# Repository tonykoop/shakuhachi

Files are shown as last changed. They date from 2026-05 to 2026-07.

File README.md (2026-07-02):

# Shakuhachi — Engineering Documentation for the Japanese End-Blown Bamboo Flute

> *A solid-billet hardwood adaptation of the shakuhachi, with parametric design for an 11-key family and a build-packet for the first prototype: 1.8-shaku D4 in cherry, bored using the headstock-driven deep-bore drilling technique on the lathe.*

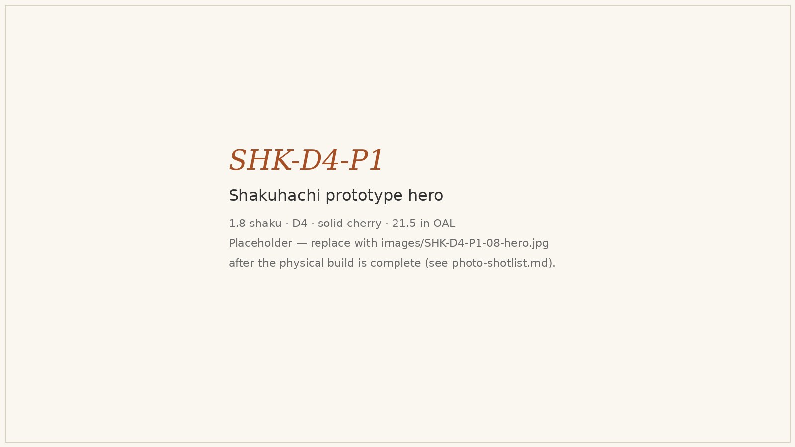
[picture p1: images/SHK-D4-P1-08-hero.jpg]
Hero — SHK-D4-P1 placeholder, replace after build

*Placeholder hero plate: SHK-D4-P1, solid cherry, 21.5 in OAL, tuned to D4. Replace this file with the canonical 35° oblique product shot after the physical build is complete — see [photo-shotlist.md](photo-shotlist.md) shot 08.*

## Release status

**Status:** L2 V5 build-packet candidate. The packet set is in place: README rewrite, design docs, BOM/sourcing/cut list/validation, assembly manual, risks, Wolfram starter, drawings, OpenSCAD reference, print/deck artifacts, and the public build-log site all exist. V5 artifacts (`visual-output-register.csv`, `cad/mcp-session-log.md`, `family-spec.csv`) added 2026-05-29.

The remaining blockers are explicit:

- **No measured prototype data yet.** `validation.csv` is a build-and-measure plan, not a filled results log.
- **Hero media is still provisional.** The current hero is a placeholder plate until SHK-D4-P1 is physically built and photographed.
- **OpenSCAD source is pending measurement confirmation.** `cad/shakuhachi_master.scad` is the current geometry source; dimensions are first-order estimates — not fabrication authority until prototype bore/utaguchi correction loop closes.

**Next action:** build SHK-D4-P1, ingest the first measured Ro fundamental with `record_measurement.py`, then either export a confirmed drawing/render set from CAD or keep the repo explicitly framed as an OpenSCAD-first prototype packet.

## What this is

Engineering documentation and parametric design for the **shakuhachi** (尺八) — a Japanese end-blown bamboo flute traditionally tuned in a minor pentatonic with five finger holes. This repository combines:

1. **A parametric design table** ([`shakuhachi-design-table.xlsx`](shakuhachi-design-table.xlsx)) covering an 11-key family (C4 through higher), with formulas that derive every build dimension from the target fundamental, plus a Wolfram-Cloud notebook spec for honkyoku phrase synthesis and meri / kari pitch-shift modeling.
2. **A build packet for SHK-D4-P1** — the first physical prototype, 1.8-shaku D4 in solid cherry. See [`design.md`](design.md) for the governing acoustic model, [`bom.csv`](bom.csv), [`cut-list.csv`](cut-list.csv), [`validation.csv`](validation.csv), and [`assembly-manual.md`](assembly-manual.md). Drawings live in [`drawings/`](drawings/), CAD masters in [`cad/`](cad/), and the public build log in [`site/index.html`](site/index.html).
3. **A practical bore-making path** tied to the still-open [headstock-driven deep-bore drilling](https://github.com/tonykoop/instrument-maker/issues/84) technique on the [`instrument-maker`](https://github.com/tonykoop/instrument-maker) backlog. The 21.5-in cherry bore is what made this technique necessary — the shakuhachi is a perfect fit for it.

Sister projects: [`flutes`](https://github.com/tonykoop/flutes) (NAF — K2 reference, not portable here), [`fujara`](https://github.com/tonykoop/fujara) (long open-pipe stave-built sister), [`transverse-flute`](https://github.com/tonykoop/transverse-flute) (slip-cast open-pipe; packet template baseline).

## Cultural attribution

The shakuhachi descends from Tang-Chinese xiao ancestors imported to Japan in the 7th–8th c., and was central to the practice of *suizen* ("blowing meditation") within the Fuke sect of Zen Buddhism (Edo-period komusō, "emptiness monks"). The Meiji government banned the Fuke sect in 1871; the instrument survived in concert and ensemble use, and modern **Kinko-ryū** and **Tozan-ryū** schools continue traditional practice. Traditional makers in Kyoto, Tokyo, and Hamamatsu still build with **madake bamboo** (*Phyllostachys bambusoides*), urushi-lined bores, and water-buffalo-horn utaguchi inlays. The instruments documented here are **Western luthier-shop adaptations** built in respect for that tradition — not faithful reproductions. Where this packet diverges from tradition (solid hardwood billet, straight bore, oil finish, no urushi) it is documented as such.

## Background — what makes a shakuhachi different

**1. Voicing comes from the utaguchi cut, not a fipple.** The shakuhachi has no fipple block, no slow-air chamber, no whistle-type window. It is a direct end-blown flute: the player rests the lower lip against the utaguchi (a beveled notch cut into the rim) and directs a focused jet of air across its outer edge. This makes the instrument acoustically simple but technically demanding — every note relies on the player's lip and breath shaping.

**2. Five tone holes and a deep modal language.** Four front holes plus one thumb hole on the back, tuned to the Kinko-ryū interval set (+0/+3/+5/+7/+10/+12 semitones above the fundamental). The minor-pentatonic shape gives the instrument its characteristic voice; microtonal pitch-bending via *meri* (chin-down) and *kari* (chin-up) extends each tonal centre by ~50–100 cents.

**3. Length is the key.** A shakuhachi tuned to D4 has the standard length of 1.8 shaku (~21.5 in / 54.5 cm) — the very name 尺八 means "1.8" (one shaku eight sun). Lower keys take longer instruments: 2.4 shaku ≈ A3, 1.6 shaku ≈ E4, etc. The packet covers an 11-key parametric family, but the build-packet first prototype anchors at the canonical 1.8-shaku D4.

## The parametric design table

The single engineering-heavy artifact is [`shakuhachi-design-table.xlsx`](shakuhachi-design-table.xlsx). Variables in column A; per-key columns flow right.

**User-set per key:** Bore ID, Wall Thickness, Utaguchi Width / Depth / Angle, Extra Length (allowance for foot trim during tuning).

**Calculated per key:**
- Acoustic length `L_acoustic = c / (2·f_fund)`
- End-correction total (foot ≈ 0.6·r, utaguchi ≈ 1.7·r empirical)
- Effective physical length `L_physical = L_acoustic − δ_total`
- Shaku-length conversion (1 shaku = 11.93 in)
- Hole positions for Ro / Tsu / Re / Chi / Ri / thumb at Kinko-ryū intervals

**Compared to the NAF design table:** the workbook does **not** apply the K2 bore-diameter correction. K2 was derived from fipple-block + slow-air-chamber NAFs; the shakuhachi has neither. K2 columns are intentionally blank for shakuhachi rows. See [`design.md` § Empirical-correction guard](design.md).

## Build packet — SHK-D4-P1

| Parameter | Value | Notes |
| --- | --- | --- |
| Fundamental | 293.665 Hz (D4) | 1.8-shaku canonical |
| Physical length | 21.50 in (54.61 cm) | 1.80 shaku |
| Bore ID | 0.787 in (20 mm) | H7 reamed from 0.5/0.625/0.75 steps |
| OD | 1.10 in | Wall ≥ 0.150 in everywhere |
| Material | cherry (qtr-sawn) | backup: hard maple, walnut |
| Tone holes | 5 (4 front + thumb) | Ø 0.276 in starting; file-tuned |
| Utaguchi | 0.787 W × 0.315 D × 32° | hand-cut + filed |
| Bore-making path  | headstock-driven deep-bore | [`instrument-maker#84`](https://github.com/tonykoop/instrument-maker/issues/84) |

**Why SHK-D4-P1 is the right first prototype**, in priority order:

1. **It's the canonical shakuhachi.** The 1.8-shaku D4 is the standard reference instrument in both Kinko-ryū and Tozan-ryū traditions. Anything else is a divergence; this one is the centre of gravity.
2. **It's the boundary condition for the family.** All other family members' physical lengths, bore IDs, and end corrections derive from the same model. SHK-D4-P1's measured fundamental refines δ_utaguchi for the rest.
3. **It exercises the deep-bore drilling technique cleanly.** 21.5 in × 0.787 in is the depth-to-diameter ratio that motivated the headstock-driven technique on the [instrument-maker backlog](https://github.com/tonykoop/instrument-maker/issues/84). Building it validates the technique alongside the instrument.
4. **It's structurally safe.** Wall thickness with the planned OD (1.10 in) is 0.157 in nominal — comfortable margin over the 0.150 in minimum even at the widest tone hole.
5. **It's empirically anchored.** Traditional 1.8 shaku ↔ D4 is well-attested across centuries of Japanese makers, so a wrong prediction is immediately and unambiguously wrong (vs. being absorbed into measurement noise on a less-canonical key).

Detail in [`design.md`](design.md), [`assembly-manual.md`](assembly-manual.md), and [`risks.md`](risks.md). The validation plan with measurement-driven empirical loop is in [`validation.csv`](validation.csv).

## Repository structure

```
shakuhachi/
├── shakuhachi-design-table.xlsx   parametric workbook (11-key family)
├── design.md                      governing model + first-prototype design
├── bom.csv                        bill of materials, 16 line items
├── sourcing.csv                   suppliers + SKUs
├── cut-list.csv                   blank → finished part operations
├── validation.csv                 measurement-driven test plan
├── assembly-manual.md             13-step shop manual
├── supplier-rfq.md                RFQ template for outside vendors
├── drawing-brief.md               drawing list, datums, tolerances
├── visual-bom-brief.md            single-sheet BOM plate spec
├── photo-shotlist.md              hero + process + detail shots
├── risks.md                       red-team risk register w/ tests
├── wolfram-starter.wl             Wolfram parametric model
├── cad/                           OpenSCAD master + readme
├── cnc/                           pipeline scope notes (out-of-scope for body)
├── drawings/                      6 SVGs (overall, bore section, utaguchi,
│                                  hole template, vise fixture, hole jig)
├── images/                        photos (populated during build)
├── evolution/                     evolution-pipeline Stage 0 intake (master
│                                  manifest, design-intent, revisions; Gate A
│                                  not yet run)
└── site/index.html                public build-log page
```

## Status

- **Repo:** packet generated, close-ready for human release review.
- **First prototype (SHK-D4-P1):** dimensions specified, validation plan written, risk register filed; **no physical build yet**.
- **Family roll-out:** queued; reads forward from the empirical correction the first measurement produces.

## How to read this repo

If you're a maker / reviewer evaluating the engineering: start with [`design.md`](design.md) § Governing Model, then [`risks.md`](risks.md), then [`assembly-manual.md`](assembly-manual.md). The CSVs are the ground truth for shop work; the SVGs in [`drawings/`](drawings/) are the manufacturing references.

If you're an outside builder: the [`site/index.html`](site/index.html) public build log is the friendly front door.

## License

Code, drawings, and design documentation: [CC BY 4.0](LICENSE).

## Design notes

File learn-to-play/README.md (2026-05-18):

# learn-to-play / Shakuhachi (D)

Starter songbook for the D shakuhachi from the build packet. Generated by the sheet-music skill.

The shakuhachi is an end-blown bamboo flute with a quiet attack, flexible pitch, and expressive meri/kari shading.

Range: **D4 - D6 (two octaves). Five-hole pentatonic core with cross-fingered diatonic notes.**

## Folder map
| Folder | Contents |
|---|---|
| `00-warmup-scales/` | D minor pentatonic range walk, breath-tone intervals, meri/kari pitch-bend drill |
| `01-easy/` | Three slow Japanese public-domain folk melodies |
| `02-intermediate/` | Two modal studies with longer breath arcs |
| `03-original/` | *Bamboo Rain* - Heifer Zephyr original |
| `fingering-charts.svg` | D minor pentatonic fingering chart, D4-D6 |

## Repertoire

### 01-easy
| Tune | Tradition |
|---|---|
| Sakura Sakura | Trad Japanese folk song (pre-1900) |
| Hotaru Koi | Trad Japanese folk song (pre-1900) |
| Kagome Kagome | Trad Japanese children's song (pre-1900) |

### 02-intermediate
| Tune | Tradition |
|---|---|
| Edo Lullaby | Trad Japanese lullaby (pre-1900) |
| Rokudan Breathing Study | Inspired by koto/shakuhachi practice forms; original study |

### 03-original
**Bamboo Rain** - 24-bar through-composed meditation, D minor pentatonic, quarter=50.

## Notes on notation
Meri/kari markings are written as comments in the ABC header. Treat grace notes as slow pitch inflections unless a note says otherwise.

## L2 readiness and known gaps
This starter songbook is ready for L2 review as a playable packet draft: ABC melodies, per-tune notes, static fingering summaries, warmups, and a top-level chart are present. Known gaps: generated audio, MusicXML, LilyPond, MIDI, and printable songsheets are skipped until the shared render dependencies are available; fingering charts need builder review against the final hole layout.

## License
Arrangements MIT-licensed by Tony Koop / Heifer Zephyr. Public-domain tune provenance is listed in each `notes.md`. Original studies are MIT-licensed for performance, recording, arrangement, and adaptation.

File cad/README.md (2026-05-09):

# `cad/` — CAD references for SHK-D4-P1

- `shakuhachi_master.scad` — parametric OpenSCAD master for the finished SHK-D4-P1 geometry. Renders the body with the bore subtracted, utaguchi notch subtracted, and five tone holes drilled at first-pass acoustic stations. Updates to the bore/length/correction parameters propagate through.

## Generate STL

```bash
openscad -o shakuhachi_d4_p1.stl shakuhachi_master.scad
```

## Notes

- The master is a **CAD reference**, not a CNC toolpath. The build path is bore-first via the headstock-driven deep-bore drilling technique (`instrument-maker#84`), followed by outside turn between centers — see `assembly-manual.md`.
- Tone-hole positions and diameters in the SCAD file are first-pass acoustic stations; the as-built instrument is bisque-style tuned and will deviate (holes 5–15 mm closer to the foot, diameters slightly enlarged via filing).
- A SolidWorks master layout (Part + Design Table) for SHK-D4-P1 is planned but not in this packet drop. When generated, it will live under `sw-reference/` with the same file naming convention as `fujara/sw-reference/`.

## Status and next handoff

- **Current source of truth in-repo:** `shakuhachi_master.scad` plus the workbook and drawing set.
- **What is intentionally missing:** no checked-in SolidWorks part/design-table handoff yet, because the first measured prototype should confirm `δ_utaguchi` before a second CAD master is frozen.
- **Next CAD action after the first build:** export one confirmed render and one dimensioned drawing from the measured geometry, then decide whether a `sw-reference/` drop adds value or just duplicates the OpenSCAD master.

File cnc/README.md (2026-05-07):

# `cnc/` — CNC toolpaths for SHK-D4-P1

This packet's primary build pipeline is **lathe + drill press**, not CNC router. The CNC pipeline is documented for completeness and for siblings that may benefit from CNC pocketing of fixture parts.

## Out-of-scope for SHK-D4-P1

- **Body bore.** The 21.5-in deep bore is drilled with the headstock-driven deep-bore drilling technique on the lathe (see `instrument-maker#84` and `assembly-manual.md` § Step 5). CNC routers cannot match the depth-to-diameter ratio without specialty tooling that doesn't make sense for a one-off prototype.
- **Body outside turn.** Between centers on the wood lathe; CNC turning a 21.5-in cylinder would be a wasted setup.
- **Tone holes.** Drill press with the V-cradle jig (SHK-BOM-007). CNC drilling on a curved cylindrical surface requires a 4-axis fixture that isn't available in Tony's shop.

## In-scope (optional, future)

- **Tailstock vise (SHK-fixture-vise) plate cutouts.** If the steel-angle vise (SHK-CUT-010) is fabricated using a CNC plasma cutter, drop the DXF in `cnc/SHK-fixture-vise.dxf`. Not required — bandsaw + drill press works.
- **Tone-hole jig V-cradle (SHK-fixture-hole-jig).** If made from MDF or plywood with a CNC router, the V-radius matching Ø 1.10 OD is easier to cut accurately than by bandsaw. DXF / 1/4-in endmill toolpath would live at `cnc/SHK-fixture-hole-jig.gcode`. Not required.

## Why this doc exists

Reviewer expectation under instrument-maker-v4 is that every packet has a `cnc/` folder with at least a README explaining the manufacturing pipeline. This file documents an explicit "no CNC for body" decision so a future agent doesn't accidentally generate CNC programs for an instrument that doesn't need them.

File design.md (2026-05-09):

# Shakuhachi — Design Document

## Source And Scope

- Date: 2026-05-07
- Repo: `tonykoop/shakuhachi`
- Source workbook (this repo): [`shakuhachi-design-table.xlsx`](shakuhachi-design-table.xlsx) — sheet `Shakuhachi`, 11-key parametric family from C4 (#40) through B4 (#50) plus higher.
- Sister design table referenced for cross-validation: `Musical Instruments V2.xlsx` → sheet `Shakuhachi`.
- Sister repos: [`flutes`](https://github.com/tonykoop/flutes) (NAF; K2 reference — see "Empirical-correction guard" below), [`fujara`](https://github.com/tonykoop/fujara) (closest open-pipe wood neighbor), [`transverse-flute`](https://github.com/tonykoop/transverse-flute) (slip-cast open-pipe — packet template).

This document is the parametric design narrative behind the rest of this build packet (`bom.csv`, `cut-list.csv`, `validation.csv`, `assembly-manual.md`, `risks.md`, drawings, site, etc.). The companion .xlsx is the editable parametric surface; `design.md` is the explanation.

## Design Intent

Build a small, manufacturable family of solid-billet shakuhachi (1.8 shaku D4 first; sized siblings later) on Tony's lathe + CNC pipeline, with the bore drilled using the **headstock-driven deep-bore drilling** technique on square stock before the outside is turned round. Document the acoustic model honestly — open-pipe physics with explicit, separately-tracked end corrections — so the first prototype's measured pitch can drive a corrections database update rather than a hand-tuned one-off. Cultural framing stays respectful and factual: this is a Western luthier-shop solid-billet build; traditional split-bamboo shakuhachi (madake, urushi-lined) is a separate craft with its own lineage.

The first prototype is **SHK-D4-P1**: 1.8-shaku solid-billet hardwood D4, no urushi lining, intentionally undersized hole bores so a bisque-style tuning step can bring it inside ±10 cents.

## Governing Model

Open-open pipe with two open ends — the lower (foot) is a free open end; the upper (utaguchi) is a beveled/notched open end with player-jet excitation. First-pass:

```text
f = c / (2 · L_eff)
L_eff = L_physical + δ_foot + δ_utaguchi
δ_foot ≈ 0.6 · r_bore                    # standard open-end correction (Levine/Schwinger)
δ_utaguchi ≈ 1.5 · r_bore to 2.0 · r_bore  # empirical shakuhachi extension; see below
hole_distance_from_foot ≈ L_eff_acoustic · (f_fund / f_hole)
```

`c = 13552 in/s` at 68 °F (1 atm dry air). `f = 440 · 2^((MIDI − 69)/12)`. `cents = 1200 · log₂(measured / target)`.

The standard NAF/Irish-flute 0.6·r end correction at the foot is well-validated. The **utaguchi** end is harder: the beveled notch + player's lip + jet airspace shift the acoustic open-point upward of the physical rim, so the *effective* extension is larger than 0.6·r. This is why a standard 1.8-shaku (21.5 in / 54.5 cm) physical length sounds D4 (293.66 Hz) — back-solving from `f = c/(2·L_eff)` gives `L_eff ≈ 23.1 in`, leaving `1.6 in` to be split between two end corrections, dominated by the utaguchi end. Per-end ≈ 1.5·r–2.0·r is the empirical band Western and Japanese makers report; it is **not** the same correction as a flanged open pipe (~0.85·r) and it is **not** the NAF K2 correction. Document it as a shakuhachi-specific empirical extension and refine after measurement.

## Empirical-correction guard

Tony's NAF K2 bore-diameter corrections (`+0.4%` at 0.875 in, `+1.0–1.6%` ≥1.125 in, `−0.7 to −6.0%` ≤0.75 in — see `flutes` and `references/acoustic-models.md` in instrument-maker-v4) were derived from 150+ Native American flutes with fipple block, slow-air chamber (SAC), and a fipple-driven embouchure. **A shakuhachi has none of those features** — no SAC, no fipple, no SAC→bore window — so K2 does not transfer. This packet uses the standard 0.6·r foot correction plus the explicit shakuhachi-specific utaguchi extension above. K2 columns in the workbook are intentionally left blank for shakuhachi rows.

## Hardware Alignment

- Pipeline: **CNC + lathe + hand-finished utaguchi**, not split-bamboo. Tony's shop is set up for solid-billet drilling and turning, and madake import is impractical for a study series.
- Bore-making strategy: **headstock-driven deep-bore drilling on square stock** ([`tonykoop/instrument-maker#84`](https://github.com/tonykoop/instrument-maker/issues/84)). The bit spins in the lathe headstock (Morse taper → Jacobs chuck); the square blank is gripped in a tailstock-mounted vise with a positive anti-rotation feature (V-block + side clamps); the tailstock quill advances the blank into the bit in short pecks. The bore is established before the outside is turned round, so the round-turning operation later registers off the established bore axis.
- Outside turn: between centers off the bore, after the bore is reamed/lapped to finish ID.
- Utaguchi: hand-cut bevel — chisel + fine file. Optional buffalo-horn or hardwood inlay (water buffalo horn = traditional; lignum vitae or African blackwood = Western substitute).
- Tone-hole boring: drill press with index-fixed jig referenced off the bore axis. Holes start undersized (~7 mm / 0.276 in) and are filed open during tuning.
- Finish: walnut oil + carnauba (food-safe inside; no urushi for the prototype). Note: traditional madake shakuhachi use *urushi* (Japanese lacquer) inside the bore — that workflow is out of scope for this packet but documented for future builds.

## Family Targets — first parametric pass

Eleven-key family from the workbook, computed at 68 °F. Hole frequencies use Kinko-ryū intervals (Ro / Tsu / Re / Chi / Ri / thumb-Ro′) at +0, +3, +5, +7, +10, +12 semitones.

| Member ID  | Key | Shaku | Fund (Hz) | L_acoustic (in) | δ_total (in) | L_physical (in) | Bore ID (in) | Bore-OD wall (in) | Status |
| --- | --- | --- | ---:| ---:| ---:| ---:| ---:| ---:| --- |
| SHK-C4-001 | C4  | 1.91 | 261.626 | 25.91  | 1.65  | 24.26  | 0.787 | 0.236 | Family — defer |
| SHK-D4-001 | D4  | 1.80 | 293.665 | 23.08  | 1.55  | 21.53  | 0.787 | 0.236 | **First prototype (SHK-D4-P1)** |
| SHK-Eb4-001| Eb4 | 1.70 | 311.127 | 21.78  | 1.50  | 20.28  | 0.787 | 0.236 | Family — queued |
| SHK-E4-001 | E4  | 1.60 | 329.628 | 20.55  | 1.45  | 19.10  | 0.787 | 0.236 | Family — queued |
| SHK-F4-001 | F4  | 1.50 | 349.228 | 19.40  | 1.30  | 18.10  | 0.669 | 0.197 | Family — queued |
| SHK-G4-001 | G4  | 1.30 | 391.995 | 17.28  | 1.20  | 16.08  | 0.669 | 0.197 | Family — queued |
| SHK-A4-001 | A4  | 1.10 | 440.000 | 15.40  | 1.10  | 14.30  | 0.591 | 0.197 | Family — queued |
| SHK-B4-001 | B4  | 1.05 | 493.883 | 13.72  | 1.00  | 12.72  | 0.591 | 0.197 | Family — queued |

Notes:
- `δ_total = δ_foot + δ_utaguchi`, with `δ_foot = 0.6·r_bore` and `δ_utaguchi` chosen empirically so `L_physical` matches the historical shaku-length tradition (D4 1.8 shaku → 21.5 in, F4 1.5 shaku → 18.0 in, etc.). The fitted `δ_utaguchi` is approximately `1.4·r_bore – 2.1·r_bore` across the family — wider than the foot correction.
- Workbook columns (`Bore ID`, `Wall Thickness`) preserve the source values: 0.787 in / 0.236 in for C4–E4, 0.669 / 0.197 for F4–G4, 0.591 / 0.197 for A4–B4.
- "Shaku" column is approximate; the historical naming (1.8, 1.6, 2.4) maps to physical length, not exactly to key. The actual first-pass `L_physical` is what feeds the cut list.

### Tone holes for SHK-D4-P1 (D4 standard 1.8-shaku)

Acoustic stations from the foot, computed as `d = L_acoustic · f₀ / f_hole`. Physical reality will be 5–15 mm shorter (i.e. holes nearer the foot) once finite-hole-diameter corrections are applied during tuning. Hole diameters start undersize and open during validation.

| Hole | Note (Kinko-ryū) | Δsemitones | f_hole (Hz) | Predicted d_foot (in) | Initial bore Ø (in) | Ergonomic notes |
| --- | --- | ---:|---:| ---:|---:| --- |
| Hole 1 (Tsu)  | F4 | +3 | 349.228 | 19.40 | 0.276  | Front, lowest finger (right pinky) |
| Hole 2 (Re) | G4 | +5 | 391.995 | 17.29 | 0.276  | Front (right ring) |
| Hole 3 (Chi)  | A4 | +7 | 440.000 | 15.40 | 0.276  | Front (left middle) |
| Hole 4 (Ri) | C5 | +10 | 523.251 | 12.95 | 0.276  | Front, highest (left index) |
| Thumb (Ro′) | D5 | +12 | 587.330 | 11.54 | 0.276  | Back, opposite/just below Hole 4 |

Tuning workflow assumes holes are **filed slightly open** (not enlarged with the drill) so each cents-flat measurement converts directly to a known file-pass action. See `assembly-manual.md` step 7 and `validation.csv` rows for SHK-D4-P1.

### Utaguchi geometry (first-pass)

| Parameter | Value | Source / rationale |
| --- | --- | --- |
| Notch width | 0.787 in | = bore ID (full bore opening) |
| Notch depth | 0.315 in | ~0.40 · bore ID — typical Kinko-ryū depth |
| Inner bevel angle | 32° | Workbook standard; Kinko-ryū makers report 28–35° |
| Outer-edge profile  | Round-over | 0.020–0.030 in radius — softens chip on overblowing |
| Inlay (optional) | 0.060 in | Buffalo horn / lignum vitae block, 0.5 in × 0.787 in × 0.060 in, mortised flush |

The utaguchi profile dominates first-prototype voicing far more than millimeter-scale bore tuning — plan time for hand-shaping iterations.

## Manufacturing Strategy (summary)

Detail in `assembly-manual.md`. Headlines:

1. Mill 1×1×24 in square hardwood blanks on the table saw + planer. Quarter-sawn cherry / hard maple / black walnut for SHK-D4-P1.
2. Center-mark both ends; cross-mark the bore axis with awl + center-finder.
3. Headstock-driven deep-bore drilling per [`instrument-maker#84`](https://github.com/tonykoop/instrument-maker/issues/84):
   - Pilot bit (3/8 in / 9.5 mm) brad-point, lathe MT2 → Jacobs chuck, square blank in tailstock vise.
   - Step up: 1/2 in (12.7 mm) → 5/8 in (15.9 mm) → 3/4 in (19.05 mm) → final 0.787 in (20 mm) reamer or step-down endmill in collet chuck.
   - Pecks ≤ 1.5 in deep; retract to clear chips.
4. Mount blank between centers using the bore as the registration axis (pin centers in the bore). Turn the outside round to 1.10 in OD — modest profile, no decorative beads on prototype.
5. Cut blank to 21.5 in finish length; square the foot end.
6. Lay out tone holes from foot using a paper wrap template; drill undersized (7 mm) on the drill press with the bore axis indexed.
7. Cut utaguchi: bandsaw rough notch → chisel inner bevel to 32° → flat-file → buffer the round-over.
8. Bisque-style tuning: stop all holes, blow Ro, measure cents — file utaguchi or bore foot to bring fundamental within range; then file each hole open in 0.5 mm steps to bring its sounded note within ±10 cents.
9. Oil finish — walnut oil flooded inside the bore and outside; let cure; carnauba wax buff outside only.

## Validation Plan

- **Stage 1 (post-bore):** measure ID at foot, mid, and top with a bore gauge; record three diameters per station to catch ovalization.
- **Stage 2 (post-turn):** measure OD at five stations; verify wall ≥ 0.150 in everywhere (avoid splitting under hole drilling).
- **Stage 3 (post-utaguchi):** blow Ro fundamental, measure with tuner against `f₀ = 293.665 Hz`. Target ±25 cents pre-tuning, ±10 cents post-tuning.
- **Stage 4 (per hole):** open one hole at a time (others closed), record cents error vs target. File open in 0.5 mm increments; remeasure.
- **Stage 5 (octave):** overblow Ro to Ro′; record cents error vs `587.330 Hz`. Octave error >25 cents indicates bore taper or utaguchi geometry; reshape rather than tone-hole-tune.

Each measurement gets a row in `validation.csv` — environment columns (temp, RH, tuner make/model) are mandatory because shakuhachi pitch shifts ~3 cents/°C.

## Open Assumptions

1. **Utaguchi correction `~1.5–2.0·r_bore` per end** is empirical and shakuhachi-specific. SHK-D4-P1 will produce a single data point; the correction will be re-fit on `record_measurement.py` ingest.
2. **Bore is straight cylindrical** (not tapered). Traditional madake shakuhachi has internal taper from the natural bamboo + urushi build-up. Solid-billet straight bore is acoustically simpler but tonally less complex; documented as a planned divergence.
3. **Hole diameters are uniform 0.276 in (7 mm) starting size**. Real shakuhachi often have slightly larger holes (8–10 mm) to flatten higher overtones. Starting smaller leaves room to file open during tuning.
4. **Wood species sensitivity not yet measured.** SHK-D4-P1 is cherry. Differences in modulus / density between cherry / hard maple / black walnut will affect the structural margin around hole walls but should not significantly affect pitch in a sealed-bore build.
5. **No urushi lining.** Western prototype is oil-sealed; pitch stability under humidity changes will be measured over 30 days but no urushi-equivalent damping correction is applied.
6. **Player calibration absorbed into utaguchi correction.** Tony is the test player; embouchure variation between players will shift measured pitch by 5–20 cents. Validation rows note "player = TK" so cross-player corrections can be added later.

## Highest-risk Unknowns

| Risk | Trigger | Test |
| --- | --- | --- |
| Bore wander on 21.5-in deep bore | Pilot bit deflection on long blank | Scrap-stock validation row; bore-axis runout check at 6/12/18″ |
| Utaguchi geometry mistuned beyond filing recovery | Bevel angle wrong, notch too deep | Cut shallow; measure fundamental; deepen incrementally |
| Wall thickness too thin around hole 4 / thumb | Wall ≈ 0.150″, hole Ø 0.394″ → 38% wall loss | Wall-thickness map post-turn; abort if any station < 0.140″ |
| Octave (Ro→Ro′) > 25 cents off | Bore-axis ≠ acoustic axis, or taper drift | Stage-5 measurement; root cause = bore, not hole |
| Foot end-correction assumption fails on shorter keys | δ_foot scales with r but utaguchi scales weakly | F4 / A4 prototypes will reveal whether δ_utaguchi is constant |

## Empirical Loop

After SHK-D4-P1 is measured, run:

```bash
python3 <instrument-maker-v4-install>/scripts/record_measurement.py \
  --packet . \
  --note-id Ro \
  --measured-hz 293.6 \
  --tuner "Korg OT-120" \
  --environment "shop, 68F, 45% RH"
```

Replace `<instrument-maker-v4-install>` with the local install path for the v4 skill/scripts bundle. This updates `validation.csv`, computes cents error vs `f₀ = 293.665`, and refines the per-family `δ_utaguchi` correction so SHK-Eb4-001 / SHK-F4-001 / etc. predictions tighten before they're cut.

## Cultural Framing

The shakuhachi (尺八) originates from Tang-Chinese xiao ancestors imported to Japan in the 7th–8th c., and was central to the practice of *suizen* ("blowing meditation") within the Fuke sect of Zen Buddhism (Edo period komusō, "emptiness monks"). The Meiji government banned the Fuke sect in 1871; the instrument survived in concert and ensemble use (sankyoku trio with koto + shamisen), and modern Kinko-ryū and Tozan-ryū schools continue traditional practice. Traditional makers in Kyoto, Tokyo, and Hamamatsu still use madake bamboo with urushi-lined bores; the instruments built from this packet are non-Slovak…—correction—non-Japanese Western luthier prototypes that respectfully model the acoustics and finger-hole logic without claiming to replicate the traditional craft. Where this packet diverges from tradition (solid billet, hardwood, straight bore, oil finish) it is documented as such.

## Cross-references

- [`tonykoop/instrument-maker#84`](https://github.com/tonykoop/instrument-maker/issues/84) — headstock-driven deep-bore drilling (technique reference).
- [`tonykoop/flutes`](https://github.com/tonykoop/flutes) — NAF family + K2 derivation (do **not** apply K2 to shakuhachi; see "Empirical-correction guard").
- [`tonykoop/fujara`](https://github.com/tonykoop/fujara) — long open-pipe stave-built sister; closest geometric neighbor.
- [`tonykoop/transverse-flute`](https://github.com/tonykoop/transverse-flute) — slip-cast open-pipe sister; packet template baseline.
- `instrument-maker-v4/references/acoustic-models.md` § "Open-Open Pipes", § "Empirical-correction guard rules".
- `instrument-maker-v4/references/techniques/headstock-driven-deep-bore-drilling.md`.

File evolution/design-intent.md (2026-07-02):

# Design Intent — shakuhachi rev A

- Master CAD: `cad/shakuhachi_master.scad` (sha256: 5e1eab587df07bde368e7b54522ce0b5beb3cecc83d5baec8c92fb0c24edd8a5), driven by `shakuhachi-design-table.xlsx` (sha256: e20c7322fb02a1b126804d6d7b2a8281e23369728cbd3b6d9807a8e49a280e54)
- Function: Solid-billet hardwood shakuhachi (Japanese end-blown bamboo flute adaptation), 11-key parametric family (C4-B4), first prototype SHK-D4-P1 (1.8-shaku D4, cherry). Open-open pipe acoustics: foot end open, utaguchi (blowing edge) end open with player-jet excitation; `f = c/(2*L_eff)`, `L_eff = L_physical + delta_foot + delta_utaguchi`. Bore drilled via headstock-driven deep-bore drilling on square stock before outside turning.
- Environment: hand-played wind instrument; walnut-oil/carnauba finish (no urushi lining for the prototype). No physical build exists yet.
- Target qty: 1 prototype (SHK-D4-P1). Deadline: TBD. Budget/unit ceiling: TBD (bom.csv line items ~$28-68 per tooling/material item).

## Critical dimensions (carry tolerances)

| Feature | Nominal | Tolerance | Why critical | Source |
| --- | --- | --- | --- | --- |
| Physical length (SHK-D4-P1) | 21.53 in | measured Ro fundamental within ±25 cents | fundamental pitch (D4, 293.665 Hz) | design.md Family Targets table (SHK-D4-001) |
| Bore ID | 0.787 in | reamed/lapped finish ID | end-correction magnitude, tone | design.md Family Targets table |
| Wall thickness at bore | 0.236 in | structural min around hole 4/thumb hole (risks.md S1) | avoid blowout during hole drilling | design.md Family Targets table |
| Utaguchi end correction (delta_utaguchi) | ~1.4-2.1 x r_bore (empirical) | pending SHK-D4-P1 measurement, ±25 cents gate | dominant term in L_eff; NOT the NAF K2 correction (risks.md A1/A2) | design.md Governing Model + Empirical-correction guard |
| Tone-hole stations (5: Tsu/Re/Chi/Ri/thumb) | see design.md hole table | filed open during tuning, not enlarged with drill | intonation of Kinko-ryu intervals | design.md "Tone holes for SHK-D4-P1" |
| Foot end correction (delta_foot) | 0.6 x r_bore | standard Levine/Schwinger open-end value | secondary L_eff term | design.md Governing Model |

## Incidental (free for DFM)

- Exterior turned profile/taper styling, optional buffalo-horn or hardwood inlay cosmetic choice (risks.md C2 provenance caveat), non-mating surface finish sheen.

## Must-nots (DFM may never violate)

- Do not apply NAF K2 bore-diameter corrections to shakuhachi rows — a shakuhachi has no SAC/fipple, so K2 does not transfer (risks.md A2, design.md Empirical-correction guard).
- Do not cut sibling family blanks (Eb4 etc.) until the corrected delta_utaguchi from SHK-D4-P1 measurement predicts the next member within ±15 cents (risks.md A1).
- Do not enlarge tone holes with a drill after the initial undersized bore — holes are filed open only, per the tuning workflow (design.md Tone holes section).
- Do not thin the wall below spec around hole 4/thumb hole (risks.md S1 structural risk).
- Utaguchi (blowing-edge) bevel geometry stays hand-refined/tuning-sensitive — out of scope for the OpenSCAD envelope model (V5 woodwind addendum).

## Material intent

- Body: quarter-sawn, kiln-dried cherry (primary), hard maple / black walnut backups (bom.csv SHK-BOM-001).
- Optional inlay: buffalo horn or lignum vitae alternative (bom.csv SHK-BOM-002; provenance caveat risks.md C2).
- Finish: walnut oil + carnauba wax (food-safe inside; no urushi lining for the prototype).
- Forbidden: none recorded beyond the cultural-attribution caveat (risks.md C1 — do not overstate traditional-lineage claims on this Western solid-billet prototype).

## Stage status

Stage 0 intake complete 2026-07-01. Gate A (Alpha shop compile) NOT yet run — no concessions logged, nothing presented as shippable. No physical prototype exists yet (SHK-D4-P1 not yet built).

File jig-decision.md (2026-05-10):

# Jig Decision

| Operation | Jig choice | Reason | Release check |
| --- | --- | --- | --- |
| Deep bore | Headstock-driven drilling setup | Long D4 body needs aligned bore support | Bore exits within tolerance and stays burn-free |
| Utaguchi cut | Angle block plus hand-file finish | Utaguchi geometry controls response | Coupon or scrap cut reviewed before body |
| Hole drilling | V-block with centerline and thumb-hole reference | Keeps five-hole pattern aligned around the body | Hole stations match drawing before enlargement |
| Bore finishing | Reamer/sanding mandrel | Smooth bore response matters more than surface shine | Bore is smooth and diameter is logged |
| Prototype material choice | PVC or hardwood proof before bamboo claim | Separates acoustic validation from traditional material complexity | Validation row identifies actual material |

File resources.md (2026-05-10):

# Resources

## Cultural And Build Context

The packet documents a contemporary workshop adaptation of the shakuhachi. It
should name traditional practice respectfully while making clear that a solid
hardwood or PVC proof body is not a faithful madake bamboo reproduction.

## Sources To Confirm Before L3

- Traditional 1.8 shaku D4 dimensional references.
- Utaguchi angle, depth, and insert geometry from measured examples.
- Kinko-ryu and Tozan-ryu fingering/tuning references for public-facing text.
- Bamboo-vs-hardwood bore correction observations from the first prototype.

## Related Repos

- `tonykoop/flutes` for wind-instrument validation habits. NAF K2 corrections
  are not portable to shakuhachi.
- `tonykoop/fujara` for long open-pipe bore and trimming discipline.
- `tonykoop/transverse-flute` for slip-cast/open-pipe documentation patterns.

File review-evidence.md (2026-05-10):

# Review Evidence

Refs #1.

## Round 3 Scope

- Re-validated the existing root-mode packet as part of the wind build-packet
  sweep.
- Existing packet already contains the key shakuhachi-specific hand tuning:
  utaguchi geometry, bamboo-vs-hardwood/PVC prototype framing, pentatonic
  Kinko-ryu interval plan, and explicit warning that NAF K2 corrections do not
  transfer.
- This packet remains L2/L3-candidate documentation, not a measured build.

## Gates Before Close

- Build SHK-D4-P1 or an equivalent proof body.
- Record Ro fundamental, meri/kari response, hole tuning, and utaguchi
  correction in `validation.csv`.
- Replace placeholder hero media with owned build photos.

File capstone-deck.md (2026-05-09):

# Shakuhachi Capstone — SHK-D4-P1

# Title
## Shakuhachi (SHK-D4-P1)
1.8-shaku D4, solid cherry, headstock-driven deep-bore drilling

Tony Koop · 2026-05-07

# Project Intent
Build a small, manufacturable family of solid-billet hardwood shakuhachi (1.8 shaku D4 first; sized siblings later) on a Western luthier's lathe + drill press, with the long bore drilled using the headstock-driven deep-bore drilling technique on square stock before the outside is turned round. Document the open-pipe acoustic model honestly — explicit foot vs utaguchi end corrections — so the first prototype's measured pitch drives a corrections database update rather than a hand-tuned one-off. This packet is a Western adaptation, not a tradition-faithful reproduction.

# Cultural Framing
Shakuhachi (尺八) descends from Tang-Chinese xiao ancestors imported to Japan in the 7th–8th c.; central to suizen ("blowing meditation") in the Fuke sect of Zen Buddhism. Banned by Meiji 1871; survives in concert use through Kinko-ryū and Tozan-ryū schools today. Traditional makers in Japan still use madake bamboo with urushi-lined bores — this packet documents a respectful Western solid-billet adaptation, not a reproduction.

# Physics Model

```
f = c / (2 · L_eff)
L_eff = L_physical + δ_foot + δ_utaguchi
δ_foot ≈ 0.6 · r_bore                    (standard open-end correction)
δ_utaguchi ≈ 1.5–2.0 · r_bore             (empirical shakuhachi extension)
hole_distance_from_foot ≈ L_acoustic · (f_fund / f_hole)
```

Open-open pipe with two open ends. Foot is a normal flange-like end. Utaguchi is harder: bevel + jet excitation extend the acoustic open-point past the rim. Back-fitting from canonical 1.8-shaku ↔ D4 gives ~1.7·r per end empirically.

**Empirical-correction guard:** Tony's NAF K2 corrections do NOT apply — shakuhachi has no fipple, no SAC. K2 columns deliberately blank.

# Hardware Alignment
- **Pipeline:** lathe + drill press + hand-finished utaguchi
- **Bore strategy:** headstock-driven deep-bore drilling on square stock — see [`instrument-maker#84`](https://github.com/tonykoop/instrument-maker/issues/84)
- **Outside turn:** between centers off bore (pin-centers register the bore axis as the lathe axis)
- **Tone holes:** drill press w/ V-cradle jig; undersize 7 mm starts, file-open during tuning
- **Utaguchi:** bandsaw rough → chisel pare to 32° bevel → mill-bastard file flat → 0.020 in round-over
- **Finish:** walnut oil bore + outside, 3–5 day cure; carnauba wax outside only

# First Prototype — SHK-D4-P1

| Parameter | Value |
| --- | --- |
| Fundamental | 293.665 Hz (D4) |
| Physical length | 21.50 in / 54.61 cm / 1.80 shaku |
| Bore ID | 0.787 in (20 mm) |
| OD | 1.10 in |
| Material | cherry, quarter-sawn |
| Wall (nominal) | 0.157 in |
| Tone holes | 5 (4 front + thumb) |
| Initial hole Ø | 0.276 in (7 mm) |

# Family Targets — 11-key parametric

| ID | Key  | Fund (Hz) | L_phys (in) | Bore ID | Status |
| --- | ---- | ---: | ---: | ---: | --- |
| SHK-C4-001 | C4 | 261.626 | 24.26 | 0.787 | family — defer |
| SHK-D4-001 | D4 | 293.665 | 21.53 | 0.787 | **first prototype** |
| SHK-Eb4-001| Eb4  | 311.127 | 20.28 | 0.787 | queued |
| SHK-E4-001 | E4 | 329.628 | 19.10 | 0.787 | queued |
| SHK-F4-001 | F4 | 349.228 | 18.10 | 0.669 | queued |
| SHK-G4-001 | G4 | 391.995 | 16.08 | 0.669 | queued |
| SHK-A4-001 | A4 | 440.000 | 14.30 | 0.591 | queued |
| SHK-B4-001 | B4 | 493.883 | 12.72 | 0.591 | queued |

# Tone-hole Stations (SHK-D4-P1, Kinko-ryū)

| Hole | Note  | Δ semi | f_hole (Hz) | d_foot (in) | Face  |
| --- | ----- | -----: | ---: | ---: | ----- |
| Hole 1 (Tsu)  | F4 | +3 | 349.228 | 19.40 | front |
| Hole 2 (Re) | G4 | +5 | 391.995 | 17.29 | front |
| Hole 3 (Chi)  | A4 | +7 | 440.000 | 15.40 | front |
| Hole 4 (Ri) | C5 | +10 | 523.251 | 12.95 | front |
| Thumb (Ro′) | D5 | +12 | 587.330 | 11.54 | back  |

Holes are first-pass acoustic stations; bisque-style filing brings each to ±10 cents.

# Build Workflow
1. Mill 3 cherry blanks, 1×1×24 in qtr-sawn
2. Build tailstock vise (one-time fixture, MT2 shank)
3. Pine-scrap validation pass: bore wander < 0.020/0.040/0.080 in @ 6/12/18 in
4. Production deep-bore: 3/8 → 1/2 → 5/8 → 3/4 → 0.787 in reamer
5. Outside turn between centers off bore, OD 1.10 in
6. Tone-hole layout: 1:1 paper-wrap template, awl-punch, drill 7 mm undersize
7. Utaguchi cut: bandsaw → chisel → file → round-over
8. Bisque-style tuning: fundamental + each hole + octave
9. Walnut-oil cure 3–5 days; carnauba wax outside
10. Final-tuner pass; record_measurement.py → empirical loop

# Drawings

Overall
Bore section
Utaguchi detail
Tone-hole template
Tailstock vise fixture
Tone-hole drill jig

# BOM Highlights

16 line items in `bom.csv`. Total estimated cost ~430 USD (excluding optional inlay + mortising chisels). Long-lead item: 20 mm × 24 in straight-flute reamer (~10 days). Hardwood blanks ship in 5–7 days.

Categories: tonewood (3 blanks), deep-bore tooling (pilot + step-up + reamer + vise), drill-press jig, tone-hole tooling (brad-points + diamond files), validation hardware (tuner + bore gauge + thermometer), finish (walnut oil + carnauba), optional inlay (buffalo horn + chisels).

# Validation Plan

- Pine-scrap pass (mandatory before production cherry)
- Post-bore: 3-station bore-ID audit + ovalization < 0.005 in
- Post-turn: wall-thickness audit (≥ 0.150 in everywhere)
- Post-utaguchi: Ro fundamental ±25 cents pre-tuning
- Per-hole: ±10 cents post-tuning each
- Octave check: Ro → Ro′ within ±25 cents
- 30-day stability: < 5 cents drift at constant 68 °F

Each measurement = a row in `validation.csv` with environment columns mandatory.

# Risks (highest five)

1. **Utaguchi end-correction wrong** → fundamental ±15-40 cents off; refit δ_utaguchi before sibling cuts.
2. **Bore wander > spec on production cherry** → switch to staged drilling from both ends.
3. **Octave error > 25 cents** → bore taper or utaguchi geometry; reshape, don't tone-hole-tune.
4. **Wall too thin around hole 4** → reject blank if any quadrant < 0.140 in.
5. **NAF K2 corrections accidentally applied** → guarded in design.md and workbook; do not.

Full register in `risks.md` — every risk has a verification test attached.

# Empirical Loop

```bash
python3 <instrument-maker-v4-install>/scripts/record_measurement.py \
  --packet . \
  --note-id Ro \
  --measured-hz 293.6 \
  --tuner "Korg OT-120" \
  --environment "shop, 68F, 45% RH"
```

Replace `<instrument-maker-v4-install>` with the local install path for the v4 skill/scripts bundle. Updates `validation.csv`, computes cents error, refits per-family `δ_utaguchi`. Sibling packets (Eb4 / E4 / F4 / G4 / A4 / B4) read the corrected value before their blanks are cut.

# Open Assumptions

- δ_utaguchi ~1.7·r is empirical; first measurement re-fits.
- Bore is straight cylindrical (not tapered like madake).
- Hole diameters uniform 0.276 in starting size.
- Wood-species sensitivity unmeasured; cherry first.
- No urushi lining; oil-finish substitute.
- Player calibration absorbed into utaguchi correction.

# Next Actions

- Order BOM SHK-BOM-001 through 010 + 013–014 (cherry, deep-bore tooling, validation, finish).
- Build tailstock vise + tone-hole jig (one-time fixtures).
- Pine-scrap validation pass.
- Cut SHK-D4-P1 cherry blank; deep-bore; outside turn; layout + drill holes; utaguchi.
- Bisque-style tune; record measurement.
- Decide F4 / A4 sibling cut order based on δ_utaguchi refit.

Replace TBDs with measured/source-backed values.

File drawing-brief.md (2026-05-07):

# Drawing Brief — SHK-D4-P1

Required drawings for the first prototype, with title block, scale, datums, critical dimensions, tolerances, and material/finish notes. SVG outputs live in `drawings/`. CAD masters live in `cad/`. CNC programs (when generated) live in `cnc/`.

## Title-block convention

Every drawing carries the same title block in the bottom-right corner:

```
Project:  Shakuhachi (SHK-D4-P1)
Drawing:  <name>
Drawn by: Tony Koop
Date:     2026-05-07
Scale:    <as marked>
Units:    Inches (mm in parens where ambiguous)
Material: <as marked>
Sheet:    1 of 1
Rev:      A — first issue
```

## Datum conventions

- Bore axis is **A** (cylindrical reference).
- Foot end-face is **B** (planar, perpendicular to A).
- Front centerline (utaguchi side) is **C** (planar, contains A).
- All longitudinal dimensions chain from datum **B** (foot end). All radial dimensions chain from **A** (bore axis).
- Thumb hole drawn on the back face is dimensioned with a "(back face)" annotation.

## Drawings list

### 1. `drawings/SHK-D4-P1-overall.svg` — overall instrument

- Side elevation (front view) of finished body, full length.
- Top of drawing = utaguchi end; bottom = foot end.
- Critical dims:
  - Overall length 21.50 in (datum B → top end-face).
  - OD 1.10 in (parallel-line callout, mid-body).
  - Bore ID 0.787 in (centered phantom-line, full length).
  - Foot-end square (datum B perpendicularity ±0.005 in).
- Scale: 1:2.

### 2. `drawings/SHK-D4-P1-bore-section.svg` — bore section A-A

- Section view through the bore axis showing inner geometry.
- Critical dims:
  - Bore length end-to-end = 21.50 in.
  - Bore ID = 0.787 in (callout shown at three stations: foot, mid 10.75, top 21.50).
  - Wall thickness shown at thinnest mid-station: 0.157 in nominal (= (1.10 − 0.787)/2).
- Section labels: A-A on overall view at 90° rotation indicator.
- Scale: 1:1.

### 3. `drawings/SHK-D4-P1-utaguchi.svg` — utaguchi detail

- Section through utaguchi notch, showing inner-bevel geometry.
- Critical dims:
  - Notch width 0.787 in (at outside surface, full bore opening).
  - Notch depth 0.315 in (vertical from outside surface).
  - Inner-bevel angle 32° (referenced to bore axis).
  - Outer-edge round-over radius 0.020–0.030 in (callout note).
  - Optional inlay block 0.787 W × 0.500 L × 0.060 D (phantom).
- Scale: 4:1.

### 4. `drawings/SHK-D4-P1-hole-layout.svg` — tone-hole layout (paper-wrap template)

- Unwrapped cylindrical surface drawn as a flat rectangle.
- Width = π · OD = π · 1.10 = 3.456 in.
- Length = 21.50 in.
- Hole-center crosshairs at:
  - Hole 1 (Tsu / F4): 19.40 in from foot, **front** centerline.
  - Hole 2 (Re / G4): 17.29 in from foot, front.
  - Hole 3 (Chi / A4): 15.40 in from foot, front.
  - Hole 4 (Ri / C5): 12.95 in from foot, front.
  - Thumb (Ro′ / D5): 11.54 in from foot, **back** centerline (= +π·OD/2 from front).
- Initial hole Ø 0.276 in (drawn as drilled-bore circles).
- Scale: 1:1 (must print full-size for paper-wrap use).

### 5. `drawings/SHK-D4-P1-blank.svg` — pre-bore blank

- Square blank 1.000 × 1.000 × 24.000 in (with 0.5 in waste at each end).
- Centerlines marked on both end faces.
- Bore axis dimension: 0.500 in from each adjacent face.
- Material spec: cherry, quarter-sawn, < 8 % MC.
- Scale: 1:4.

### 6. `drawings/SHK-fixture-vise.svg` — tailstock vise / square-stock carrier

- Top view + side view of the welded fixture.
- Critical dims:
  - V-channel angle 90° internal.
  - V-channel length 6.0 in.
  - Side-clamp screws 3/8-16, two pcs at 1.5 in and 4.5 in from inboard end.
  - Morse-taper shank: MT2 (or MT3 if Tony's lathe is MT3) — note variant on print.
  - Centerline runout to spindle axis < 0.005 in.
- Scale: 1:2.

### 7. `drawings/SHK-fixture-hole-jig.svg` — tone-hole drill-press jig

- V-cradle with sliding stop; index pin on back face for thumb-hole rotation.
- Cradle V-radius matches Ø 1.10 OD.
- Index pin offset = π · OD / 2 = 1.728 in (clocks the body 180° for back-side thumb hole).
- Sliding stop graduated in 0.05 in increments from 0 (foot reference) to 21.50 in.
- Scale: 1:2.

## Tolerance philosophy

- Bore ID: H7 (+0.000 / +0.0008 in) is the target — slight oversize on the reamer is acceptable; oversize is corrected by re-fitting acoustic predictions, not by re-cutting the bore.
- OD: ±0.010 in.
- Hole positions (longitudinal): ±0.020 in pre-tuning. Post-tuning, the radial-edge file marks are not dimensional; only the center-of-mass position is meaningful.
- Hole diameters: pre-tuning ±0.005 in (drilled). Post-tuning Ø not specified — final hole geometry is whatever the chromatic tuner accepts.
- Utaguchi angle: ±2° pre-tuning. Re-finishing during Step 9 of the assembly manual is expected.

## Cross-references

- Hole-layout SVG must match `cut-list.csv` rows SHK-CUT-004 through SHK-CUT-008.
- Utaguchi detail must match `bom.csv` SHK-BOM-002 / SHK-BOM-009.
- Vise + jig drawings cross-reference [`tonykoop/instrument-maker#84`](https://github.com/tonykoop/instrument-maker/issues/84) and `references/techniques/headstock-driven-deep-bore-drilling.md`.

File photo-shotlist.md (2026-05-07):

# Photo Shot List — SHK-D4-P1

Twelve canonical shots that feed the README hero, capstone deck, print packet, build-log site, and visual BOM. Shoot in this order so the build-log site reads chronologically.

## Setup

- Camera: phone (iPhone 13 Pro or equivalent) is fine; resolution ≥ 12 MP.
- Lighting: north-facing window during daytime, supplemented by a 5500 K LED soft-box from camera-left at 45°.
- Background: neutral off-white seamless paper for product shots; in-shop context for process shots.
- Color reference: include an X-Rite ColorChecker or grey card in the first frame of each session.
- File naming: `SHK-D4-P1-<step>-<descriptor>.jpg` (e.g. `SHK-D4-P1-04-bore-validation-pine.jpg`).
- Output paths: hero + finished shots → `images/`; process shots → `images/build/`; SVG drawings → `drawings/`.

## Shot list

### 01 — Pre-build (materials)

- **01a.** Three cherry blanks stacked, end-grain visible, with caliper dimensioning the 1×1 face. Filename: `SHK-D4-P1-01-blanks.jpg`. Caption: *"Three quarter-sawn cherry blanks, 1×1×24 in. The deep-bore drilling step is more forgiving on quarter-sawn than flat-sawn stock."*
- **01b.** Tooling group photo: pilot bit + step-up bits + 20 mm reamer + tailstock vise. Filename: `SHK-D4-P1-01-tooling.jpg`. Caption: *"Deep-bore tooling for the 21.5-in cherry bore. Reamer is 24 in OAL."*

### 02 — Fixture build (one-time)

- **02a.** Tailstock vise welded up, side view on workbench with calipers indicating the V-channel internal angle. Filename: `SHK-D4-P1-02-fixture-vise.jpg`. Caption: *"Welded vise: 6 in V-channel, two 3/8-16 side clamps, MT2 shank. Built once; reusable across the family."*
- **02b.** Vise mounted on lathe tailstock with pine scrap clamped, runout dial indicator on body. Filename: `SHK-D4-P1-02-fixture-runout.jpg`. Caption: *"Indicating < 0.005 in runout to spindle axis before any production drilling."*

### 03 — Drilling (process)

- **03a.** Pine scrap mid-bore on the lathe, drill bit advancing from headstock. Filename: `SHK-D4-P1-03-scrap-bore.jpg`. Caption: *"Scrap-stock validation pass — pine, same fixture, same depth as production. Mandatory before each cherry blank."*
- **03b.** Cherry blank mid-step-up bore. Wide shot showing lathe + chip evacuation. Filename: `SHK-D4-P1-03-cherry-bore.jpg`. Caption: *"Stepping up the bore in 4 mm increments. 1/2 → 5/8 → 3/4 → 0.787 in reamer. Pecks ≤ 1.5 in."*
- **03c.** Bore-gauge measurement at the foot end immediately after the reamer pass. Filename: `SHK-D4-P1-03-bore-gauge.jpg`. Caption: *"Post-bore validation: 0.787 in ± 0.005 in at three stations, 120° apart at each station to catch ovalization."*

### 04 — Outside turn (process)

- **04a.** Body mounted between centers (registered off the bore via pin-centers). Filename: `SHK-D4-P1-04-between-centers.jpg`. Caption: *"Outside turn registered off the established bore. Bore axis = lathe rotation axis = acoustic axis."*
- **04b.** Roughing-gouge cut shaping the OD; chips flying. Filename: `SHK-D4-P1-04-roughing.jpg`. Caption: *"Rough to 1.20 in OD, finish to 1.10 in OD with a spindle gouge."*

### 05 — Hole layout and drilling

- **05a.** Paper-wrap template wrapped around the body, taped, with awl punching hole-1 center. Filename: `SHK-D4-P1-05-template.jpg`. Caption: *"Tone-hole template wrapped at 1:1 scale. Punched centers transfer to the body."*
- **05b.** Body in tone-hole jig on drill press, 7 mm brad-point bit at hole 3 station. Filename: `SHK-D4-P1-05-drilling.jpg`. Caption: *"V-cradle jig drills front and back holes from the same axis. All holes start undersize at 7 mm."*

### 06 — Utaguchi cut

- **06a.** Bandsaw rough-cut on the utaguchi notch. Filename: `SHK-D4-P1-06-bandsaw.jpg`. Caption: *"Rough notch — bandsaw, 0.030 in finishing stock left."*
- **06b.** Chisel + 32° gauge paring the inner bevel. Filename: `SHK-D4-P1-06-chisel-gauge.jpg`. Caption: *"32° gauge against the inner bevel. Cut shallow first; deepen during tuning."*

### 07 — Tuning (process)

- **07a.** Body horizontal on bench, tuner reading the fundamental, hands holding the body to blow. Filename: `SHK-D4-P1-07-tuning-fundamental.jpg`. Caption: *"Bisque-style tuning. Fundamental Ro / D4. Pre-tune target ±25 cents; post-tune ±10 cents."*
- **07b.** Diamond round file mid-stroke, opening hole 3. Filename: `SHK-D4-P1-07-filing-hole.jpg`. Caption: *"Hole-tuning workflow: file open in 0.5 mm steps, re-measure, repeat. Never enlarge with the drill."*

### 08 — Finished hero

- **08.** SHK-D4-P1 finished, oblique view at 35°, neutral seamless background, one-light setup. Filename: `SHK-D4-P1-08-hero.jpg`. **This is the README hero image.** Caption: *"SHK-D4-P1 — solid cherry, 21.5 in OAL. Bore drilled with the headstock-driven technique; oil-finished; tuned to D4."*

### 09 — Detail shots

- **09a.** Utaguchi close-up, 4:1 macro, side-light. Filename: `SHK-D4-P1-09-utaguchi.jpg`. Caption: *"Utaguchi: 0.787 in wide, 0.315 in deep, 32° inner bevel."*
- **09b.** Foot end, perpendicular view. Filename: `SHK-D4-P1-09-foot.jpg`. Caption: *"Foot end — squared to bore axis ±0.005 in. Acoustic open end."*
- **09c.** Tone-hole cluster, oblique. Filename: `SHK-D4-P1-09-holes.jpg`. Caption: *"Front holes 1–4 (Tsu / Re / Chi / Ri). Each filed to within ±10 cents of target."*

### 10 — Family overview (forward-looking)

- **10.** SHK-D4-P1 next to D4 1.8-shaku reference (any Japanese-made shakuhachi available for comparison; if none, leave this slot blank in the deck and mark "no reference instrument on hand"). Filename: `SHK-D4-P1-10-family.jpg`. Caption: *"SHK-D4-P1 next to a 1.8-shaku reference shakuhachi. Same key, different lineage."* (Skip if no reference available; the deck handles a missing image gracefully.)

## Diversion: AI-generated concept renders

If shop time is limited and a finished prototype isn't in hand, the build-log site and capstone deck can use AI-generated concept renders **clearly captioned** `AI-GENERATED CONCEPT — final instrument may differ`. Acceptable for hero placement only; never for measurement-traceable detail shots (utaguchi, hole layout, bore section).

## Cross-references

- Hero image (08) feeds README, capstone-deck "Title" slide, print-packet cover, build-log "Hero" cell.
- Detail shots (09a–c) feed capstone-deck "Drawings" slide and visual-BOM cells.
- Process shots (03a–b, 04a–b, 05a–b, 06a–b, 07a–b) feed build-log site walkthrough and capstone-deck "Build Workflow" slide.

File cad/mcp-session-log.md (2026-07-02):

# CAD / MCP Session Log — shakuhachi

`cad/shakuhachi_master.scad` was generated by a prior sprint agent (not an interactive OpenSCAD MCP
server session). It was self-authored as parametric OpenSCAD source. No Blender MCP, Illustrator MCP,
image-gen, or other external creative-tool session has produced artifacts in this packet.

All SVGs in `drawings/` were derived from the OpenSCAD source by a prior sprint agent without an
interactive MCP session.

When an OpenSCAD MCP, Blender MCP, or image-gen session produces or modifies a repo artifact,
add a row to the table below before committing that artifact.

| session_id | tool | input_authority | outputs | role | authority_result | review_status | notes |
|---|---|---|---|---|---|---|---|
| — | — | — | — | — | — | — | No interactive tool sessions recorded. scad source was sprint-agent-authored. |
| sg2-wolfram-embed-epic197 | claude-code | design.md, shakuhachi-starter.wl | wolfram/shakuhachi-wolfram-model.wl, explorer.html | analysis_source | derived_preview | unreviewed | Interactive open-open-pipe acoustic model deployed to the live explorer embed; source-only, not executed via wolframscript in this pass. |
| fable-v5-refresh-2026-07-01 | claude-code (Fable 5) | shakuhachi-design-table.xlsx | bom.csv, cut-list.csv, validation.csv, family-spec.csv | packet_refresh | fabrication | self_checked | V5 refresh pass: tabular packet data reviewed against design table; no dimension changes made. README Status line reformatted (was `**Status: L2 ...**` with colon inside bold). cad/shakuhachi_master.scad kept as-is (existing real master; utaguchi/blowing-edge geometry stays out of scope). |
| fable-v5-refresh-2026-07-01 | claude-code (Fable 5) + OpenSCAD CLI | cad/shakuhachi_master.scad (unchanged) | cad/shakuhachi_master.scad | cad_authoring | pending_measurement | self_checked | Render check only (existing master not rewritten per V5 woodwind addendum). openscad render check: pass (openscad -o STL, exit 0). |

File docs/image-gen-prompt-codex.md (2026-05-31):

# Image Generation Prompt

Concept image only; not fabrication authority. Do not include cut-ready dimensions, hole locations, or toolpaths.

## Hero Prompt

Photorealistic 3/4 studio product photograph of the SHK-D4-P1 shakuhachi prototype as a solid-billet Western luthier-shop adaptation: a straight cylindrical cherry hardwood body with warm oil finish, five simple finger holes, a carefully cut utaguchi blowing notch at the top rim, subtle hand-shaped edges, no decorative beads, and a modest natural wood grain. Show it upright and slightly angled on a clean neutral background with soft directional studio lighting, realistic 21.5-inch flute scale cues, high detail, 50mm lens look, photorealistic.

## In-Context Prompt

Photorealistic scene of the cherry shakuhachi being held vertically by a player in a quiet woodworking studio or small acoustic room, the lower lip near the utaguchi notch, four front holes visible, natural window light across the oiled hardwood, a bore gauge and tuning notebook on the bench nearby. The mood should be respectful and calm, showing a Western prototype inspired by shakuhachi acoustics without claiming traditional madake craft.

## Detail / Macro Prompt

Macro photorealistic close-up of the shakuhachi utaguchi: the beveled notch in the cherry rim, soft round-over, clean inner bore, oil-finished end grain, and the first finger hole softly blurred down the body. Use shallow depth of field and crisp wood texture, with no measurement marks or tuning labels.

## Negative / Avoid

No text, no watermarks, no brand logos, no extra limbs, anatomically plausible hands if shown, no bamboo root exaggeration, no lacquered traditional maker claims, no hole-location diagrams, no dimensions, no toolpaths.

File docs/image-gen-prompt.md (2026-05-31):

# Image-Gen Prompts

Concept image only; not fabrication authority. Do not include cut-ready dimensions, hole locations, or toolpaths.

## Hero Prompt

A single end-blown Japanese-style shakuhachi flute presented as a finished, real physical object: a slender straight cylindrical tube roughly the length of a forearm, turned from a solid billet of warm reddish-brown cherry hardwood with visible fine straight grain and a hand-rubbed satin oil finish, not bamboo and not lacquered. The defining feature is the utaguchi — a clean beveled crescent notch cut into the rim of the top (blowing) end, where the player's lip rests; it reads as a single oblique chamfer carved into the wall, optionally fitted with a small flush dark inlay block at the cut edge. The body is a smooth simple profile with no keys, no fipple, no whistle window, no mouthpiece — just the open notched top end and a plain squared open foot at the bottom. Down the front face sit four small round finger holes and one thumb hole on the back, drilled clean, no hardware. Realistic scale cues from being held upright like a recorder. Clean neutral light-grey studio background, soft directional studio light raking across the grain, three-quarter product-photography angle at about 35 degrees from horizontal, ~50mm lens, high detail, photorealistic, no text labels.

## In-Context Prompt

The same solid-cherry shakuhachi resting on a luthier's workbench in a warm wood shop, staged mid-build alongside a long straight-flute reamer and a chromatic tuner, soft natural light from a north-facing window raking across shavings and the satin-oiled body, shallow depth of field with the beveled utaguchi notch in crisp focus and the bench tooling falling soft behind. Environmental storytelling of a Western luthier-shop adaptation of a traditional instrument. Concept visualization only.

## Detail Prompt

Macro close-up of the utaguchi: the beveled crescent notch carved into the rim of the blowing end of a solid cherry hardwood tube, showing the single clean inner bevel angle, the gently rounded outer edge, the smooth bore wall behind the cut, and the optional flush dark inlay block seated at the cutting edge. Raking side light to reveal the hand-filed bevel surface, the wood grain, and the satin oil sheen. High detail, photorealistic, no measurements, no angle callouts.

## Negative / Avoid

No text, logos, watermarks, or fake maker marks; no dimension lines, angle callouts, or tuning numbers; no bamboo nodes/segments or split-cane construction; no fipple, whistle window, or recorder mouthpiece; no keys or metal mechanism; anatomically plausible hands if a player is shown.

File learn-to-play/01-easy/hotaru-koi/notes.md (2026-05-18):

# Hotaru Koi

**Tradition/source:** Trad Japanese folk song (pre-1900)
**Public domain:** Yes - pre-1929 US or original MIT
**Arrangement:** Starter L2 arrangement for `shakuhachi`.

## Range check
D4-D5: within the beginner starter range for this packet.

## Practice tip
Shape the final D as one long exhale.

## Known gaps
Audio, MusicXML, LilyPond, and printable songsheet stages are intentionally skipped until the shared render toolchain is installed. Fingering SVGs are static L2 review artifacts and should be checked against the final drilled hole layout before public release.

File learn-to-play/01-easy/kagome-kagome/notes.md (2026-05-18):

# Kagome Kagome

**Tradition/source:** Trad Japanese children's song (pre-1900)
**Public domain:** Yes - pre-1929 US or original MIT
**Arrangement:** Starter L2 arrangement for `shakuhachi`.

## Range check
D4-C5: within the beginner starter range for this packet.

## Practice tip
Keep the pulse gentle; the melody should feel circular.

## Known gaps
Audio, MusicXML, LilyPond, and printable songsheet stages are intentionally skipped until the shared render toolchain is installed. Fingering SVGs are static L2 review artifacts and should be checked against the final drilled hole layout before public release.

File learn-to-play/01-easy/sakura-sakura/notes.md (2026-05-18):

# Sakura Sakura

**Tradition/source:** Trad Japanese folk song (pre-1900)
**Public domain:** Yes - pre-1929 US or original MIT
**Arrangement:** Starter L2 arrangement for `shakuhachi`.

## Range check
D4-A4: within the beginner starter range for this packet.

## Practice tip
Use a soft attack and let the repeated tones bloom instead of punching them.

## Known gaps
Audio, MusicXML, LilyPond, and printable songsheet stages are intentionally skipped until the shared render toolchain is installed. Fingering SVGs are static L2 review artifacts and should be checked against the final drilled hole layout before public release.

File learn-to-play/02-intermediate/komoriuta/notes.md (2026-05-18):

# Edo Lullaby

**Tradition/source:** Trad Japanese lullaby (pre-1900)
**Public domain:** Yes - pre-1929 US or original MIT
**Arrangement:** Starter L2 arrangement for `shakuhachi`.

## Range check
D4-F5: within the beginner starter range for this packet.

## Practice tip
Let the rests speak; shakuhachi phrasing needs silence as much as notes.

## Known gaps
Audio, MusicXML, LilyPond, and printable songsheet stages are intentionally skipped until the shared render toolchain is installed. Fingering SVGs are static L2 review artifacts and should be checked against the final drilled hole layout before public release.

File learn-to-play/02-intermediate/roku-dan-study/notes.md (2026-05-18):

# Rokudan Breathing Study

**Tradition/source:** Inspired by koto/shakuhachi practice forms; original study
**Public domain:** Needs manager provenance review
**Arrangement:** Starter L2 arrangement for `shakuhachi`.

## Range check
D4-D5: within the beginner starter range for this packet.

## Practice tip
Play each two-bar cell in one breath before trying the full line.

## Known gaps
Audio, MusicXML, LilyPond, and printable songsheet stages are intentionally skipped until the shared render toolchain is installed. Fingering SVGs are static L2 review artifacts and should be checked against the final drilled hole layout before public release.

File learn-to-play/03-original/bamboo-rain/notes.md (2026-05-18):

# Bamboo Rain

**Tradition/source:** Tony Koop / Heifer Zephyr (2026)
**Public domain:** Yes - pre-1929 US or original MIT
**Arrangement:** Starter L2 arrangement for `shakuhachi`.

## Range check
D4-G5: within the beginner starter range for this packet.

## Practice tip
Hold the low D like a drone between phrases; the tune is about patience, not speed.

## Known gaps
Audio, MusicXML, LilyPond, and printable songsheet stages are intentionally skipped until the shared render toolchain is installed. Fingering SVGs are static L2 review artifacts and should be checked against the final drilled hole layout before public release.

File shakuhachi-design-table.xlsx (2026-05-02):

Shakuhachi (End-Blown) |  | Key →
Variable | Unit | 40 | 41 | 42 | 43 | 44 | 45 | 46 | 47 | 48 | 49 | 50 | 51 | 52 | 53 | 54 | 55 | 56 | 57 | 58 | 59 | 60 | 61 | 62 | 63 | 64
Key Name |  | C 4 | Db 4 | D 4 | Eb 4 | E 4 | F 4 | Gb 4 | G 4 | Ab 4 | A 4 | Bb 4 | B 4 | C 5 | Db 5 | D 5 | Eb 5 | E 5 | F 5 | Gb 5 | G 5 | Ab 5 | A 5 | Bb 5 | B 5 | C 6
Piano Key # |  | 40 | 41 | 42 | 43 | 44 | 45 | 46 | 47 | 48 | 49 | 50 | 51 | 52 | 53 | 54 | 55 | 56 | 57 | 58 | 59 | 60 | 61 | 62 | 63 | 64
PHYSICAL DIMENSIONS
Blank Length | in
Blank Width | in
Blank Thickness | in
Bore ID | in | 0.787 | 0.787 | 0.787 | 0.787 | 0.787 | 0.669 | 0.669 | 0.669 | 0.669 | 0.669 | 0.551 | 0.551 | 0.551 | 0.551 | 0.551 | 0.472 | 0.472 | 0.472 | 0.472 | 0.472 | 0.394 | 0.394 | 0.394 | 0.394 | 0.394
Wall Thickness | in | 0.236 | 0.236 | 0.236 | 0.236 | 0.236 | 0.197 | 0.197 | 0.197 | 0.197 | 0.197 | 0.177 | 0.177 | 0.177 | 0.177 | 0.177 | 0.157 | 0.157 | 0.157 | 0.157 | 0.157 | 0.138 | 0.138 | 0.138 | 0.138 | 0.138
Turned Diameter | in
Utaguchi Width | in | 0.787 | 0.787 | 0.787 | 0.787 | 0.787 | 0.669 | 0.669 | 0.669 | 0.669 | 0.669 | 0.551 | 0.551 | 0.551 | 0.551 | 0.551 | 0.472 | 0.472 | 0.472 | 0.472 | 0.472 | 0.394 | 0.394 | 0.394 | 0.394 | 0.394
Utaguchi Depth | in | 0.315 | 0.315 | 0.315 | 0.315 | 0.315 | 0.268 | 0.268 | 0.268 | 0.268 | 0.268 | 0.220 | 0.220 | 0.220 | 0.220 | 0.220 | 0.189 | 0.189 | 0.189 | 0.189 | 0.189 | 0.158 | 0.158 | 0.158 | 0.158 | 0.158
Utaguchi Angle | deg | 32 | 32 | 32 | 32 | 32 | 32 | 32 | 32 | 32 | 32 | 32 | 32 | 32 | 32 | 32 | 32 | 32 | 32 | 32 | 32 | 32 | 32 | 32 | 32 | 32
Extra Length | in | 0.750 | 0.750 | 0.750 | 0.750 | 0.750 | 0.750 | 0.750 | 0.750 | 0.750 | 0.750 | 0.750 | 0.750 | 0.750 | 0.750 | 0.750 | 0.750 | 0.750 | 0.750 | 0.750 | 0.750 | 0.750 | 0.750 | 0.750 | 0.750 | 0.750
ACOUSTIC CALCULATIONS
Acoustic Length | in
End Correction (×2) | in
Effective Length | in
Speed of Sound (68°F) | in/s | 13552 | 13552 | 13552 | 13552 | 13552 | 13552 | 13552 | 13552 | 13552 | 13552 | 13552 | 13552 | 13552 | 13552 | 13552 | 13552 | 13552 | 13552 | 13552 | 13552 | 13552 | 13552 | 13552 | 13552 | 13552
Shaku Length | shaku
MINOR PENTATONIC (Kinko-ryū)
Fundamental Note (Ro) |  | C 4 | Db 4 | D 4 | Eb 4 | E 4 | F 4 | Gb 4 | G 4 | Ab 4 | A 4 | Bb 4 | B 4 | C 5 | Db 5 | D 5 | Eb 5 | E 5 | F 5 | Gb 5 | G 5 | Ab 5 | A 5 | Bb 5 | B 5 | C 6
Fundamental Freq | Hz
Hole 1 Note (Tsu, +3) |  | Eb 4 | E 4 | F 4 | Gb 4 | G 4 | Ab 4 | A 4 | Bb 4 | B 4 | C 5 | Db 5 | D 5 | Eb 5 | E 5 | F 5 | Gb 5 | G 5 | Ab 5 | A 5 | Bb 5 | B 5 | C 6 | Db 6 | D 6 | Eb 6
Hole 1 Freq | Hz
Hole 1 Diameter | in
Hole 1 Dist from End | in
Hole 2 Note (Re, +5) |  | F 4 | Gb 4 | G 4 | Ab 4 | A 4 | Bb 4 | B 4 | C 5 | Db 5 | D 5 | Eb 5 | E 5 | F 5 | Gb 5 | G 5 | Ab 5 | A 5 | Bb 5 | B 5 | C 6 | Db 6 | D 6 | Eb 6 | E 6 | F 6
Hole 2 Freq | Hz
Hole 2 Diameter | in
Hole 2 Dist from End | in
Hole 3 Note (Chi, +7) |  | G 4 | Ab 4 | A 4 | Bb 4 | B 4 | C 5 | Db 5 | D 5 | Eb 5 | E 5 | F 5 | Gb 5 | G 5 | Ab 5 | A 5 | Bb 5 | B 5 | C 6 | Db 6 | D 6 | Eb 6 | E 6 | F 6 | Gb 6 | G 6
Hole 3 Freq | Hz
Hole 3 Diameter | in
Hole 3 Dist from End | in
Hole 4 Note (Ri, +10) |  | Bb 4 | B 4 | C 5 | Db 5 | D 5 | Eb 5 | E 5 | F 5 | Gb 5 | G 5 | Ab 5 | A 5 | Bb 5 | B 5 | C 6 | Db 6 | D 6 | Eb 6 | E 6 | F 6 | Gb 6 | G 6 | Ab 6 | A 6 | Bb 6
Hole 4 Freq | Hz
Hole 4 Diameter | in
Hole 4 Dist from End | in
Thumb Hole Note (Ro oct, +12) |  | C 5 | Db 5 | D 5 | Eb 5 | E 5 | F 5 | Gb 5 | G 5 | Ab 5 | A 5 | Bb 5 | B 5 | C 6 | Db 6 | D 6 | Eb 6 | E 6 | F 6 | Gb 6 | G 6 | Ab 6 | A 6 | Bb 6 | B 6 | C 7
Thumb Hole Freq | Hz
Thumb Hole Diameter | in
Thumb Hole Dist from End | in
WOLFRAM CLOUD NOTEBOOK SPEC — SHAKUHACHI
Japanese end-blown bamboo flute — utaguchi (mouthpiece) cut + meri/kari (head tilt) for microtonal pitch bending.
§1 — HISTORY, ETYMOLOGY & ORIGIN
Origin: ancestor instruments from China (xiao-family) introduced to Japan ~7–8th c. (Nara period). Edo-period komusō ('emptiness monks') of Fuke Zen used shakuhachi for suizen ('blowing meditation') — banned by Meiji government 1871; survived as concert and ensemble instrument (sankyoku trio with koto + shamisen).
Shakuhachi' = 1.8 (one shaku eight sun) — the 'standard' D4 flute is 1.8 shaku long (~54.5 cm). Other lengths take their key from their length: 2.4 shaku = A3, 1.6 shaku = E4, etc.
Wolfram items: GeoGraphics China→Japan arc; TimelinePlot[{700, 1300, 1614, 1871, 1950s}→{Tang xiao import, Komusō rise, Fuke sect codified, Meiji ban, modern revival}]; Entity["MusicalInstrument","Shakuhachi"].
§2 — PHYSICS & ACOUSTICS
Open-open pipe: f = c/(2 L_eff), but utaguchi cut + 5-hole sparse fingering means each note relies heavily on player's lip + breath shaping.
Meri / kari: chin-down (meri) or chin-up (kari) head tilt shifts the embouchure jet relative to utaguchi edge — lowers/raises pitch by ~50–100 cents. Built into the playing technique, not the geometry.
Bamboo bore is irregular (root end is wider, internal nodes partially planed); use Webster horn equation rather than ideal cylinder.
Wolfram functions: NDSolve Webster horn equation; Periodogram on recorded notes; FindPeaks for multi-phonic / partial analysis; NonlinearModelFit for effective end correction.
§3 — GEOMETRY & DESIGN MODEL
Length 1.8 shaku = 54.5 cm; 5 holes (4 front + 1 thumb back); utaguchi = chamfered notch on blowing edge with hardwood/buffalo-horn inlay.
Bore profile: traditional bamboo (madake), CNC-routed from split blank for synthetic versions. Internal taper: gradual narrowing toward foot.
Wolfram items: Manipulate sliders for L, hole_x_i, bore_diameter; ParametricPlot3D bore as surface of revolution with non-cylindrical r(z); Graphics for utaguchi cross-section.
§4 — MATERIALS & CORRECTIONS
Madake bamboo (Phyllostachys bambusoides) — preferred. Root end provides natural taper. ρ ≈ 700–900 kg/m³, with internal urushi lacquer coating to seal/tune the bore.
Urushi (Japanese lacquer): seals bore, evens out internal diameter, slightly raises Q. Multiple layers; each pair of coats raises pitch ~5–10 cents.
Synthetic alternative: ABS plastic, CNC wood, or 3D printed. Synthetic is more uniform but lacks the irregular nodes that give bamboo its character.
Temperature: cold flute plays flat ~3 cents/°C; humidity affects bamboo more than synthetic.
§5 — BOM HOOK & MAP
SemanticImport["Flutes-AI.xlsx","Shakuhachi"]; group BOM by build path (bamboo vs CNC synthetic).
Map: highlight Kyoto, Tokyo, Hamamatsu (modern makers); Edo komusō pilgrimage routes.
§6 — ANIMATED DIAGRAMS
Meri/kari animation: Animate showing chin angle → jet vector → effective length → pitch shift; tie to a Listen[ ] sample if Audio resources are loaded.
Standing wave Animate: pressure profile in non-cylindrical bore; show how non-cylindrical shape distorts ideal sin profile.
Utaguchi cross-section Manipulate: angle, depth, inlay material → shows attack and edge tone behavior.
§7 — EXECUTABLE CELLS
lShakuhachi[f_,bore_]:=343/(2 f) - 0.6 bore (* m *)
shakuToCm[s_]:=s 30.3 (* 1 shaku = 30.3 cm; 1 sun = 3.03 cm *)
meriShift[θ_]:=cents per degree fit from data (* empirical *)
validate: AudioRecord Ro/Tsu/Re/Chi/Ri (the five basic notes) → Periodogram → cents error vs equal temperament + traditional Edo tuning.
§8 — DEPLOYMENT
CloudDeploy: shakuhachi length-from-key calculator; FormFunction for desired key + bore taper → hole positions and utaguchi placement.
Wolfram functions: CloudDeploy, APIFunction, FormFunction, AudioCapture, Periodogram, Export[ ,"CDF"|"PDF"].
WOLFRAM EXPLORATIONS — SHAKUHACHI
Curated from the wolfram-notebooks-roadmap brainstorm — pick a row, file an issue, build the notebook.
Roadmap-inspired notebook ideas tailored to this sheet:
• Meri/Kari Pitch Map — Empirical model of chin-tilt angle → cents shift; calibrate to player's embouchure; tablet trainer.
• Bamboo Bore Variability (Webster Horn) — Real-world madake r(z) profiles vs idealized cylinder; explain why each bamboo blank is unique.
• Urushi Layer Pitch-Stabilization — Predict cents shift per pair of urushi coats; tracks empirical 5–10 cents/coat rule.
• Honkyoku Phrase Synth — Synthesize traditional komusō phrases (Mukaiji, Koku, Kyorei) with breath-noise + meri/kari modulation.
• Cultural Atlas: Edo-Period Komusō Routes — GeoGraphics historical pilgrimage circuits; TimelinePlot Tang xiao import → Fuke ban → modern revival.

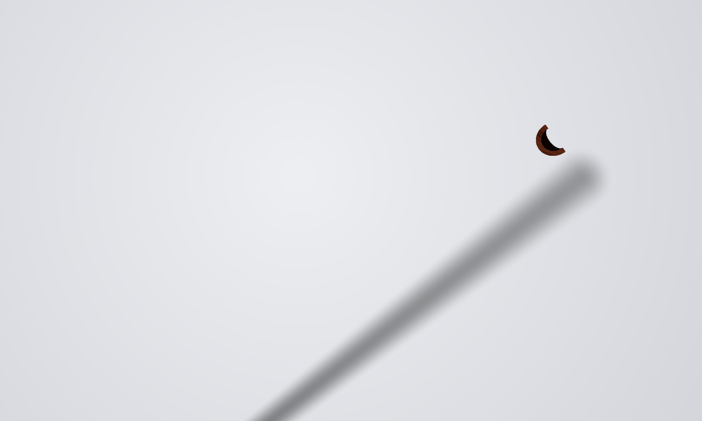
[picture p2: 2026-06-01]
images/hero-render.png

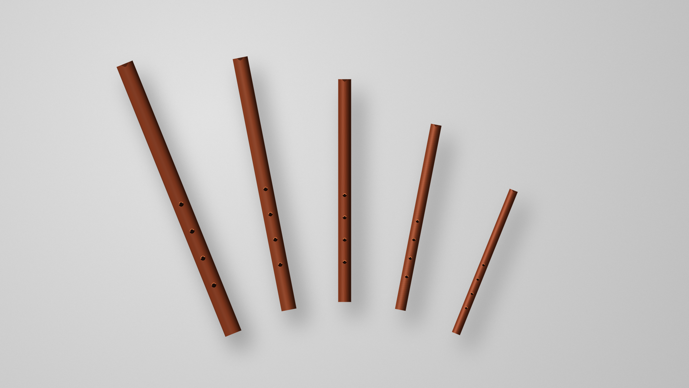
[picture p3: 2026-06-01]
images/family-group.png

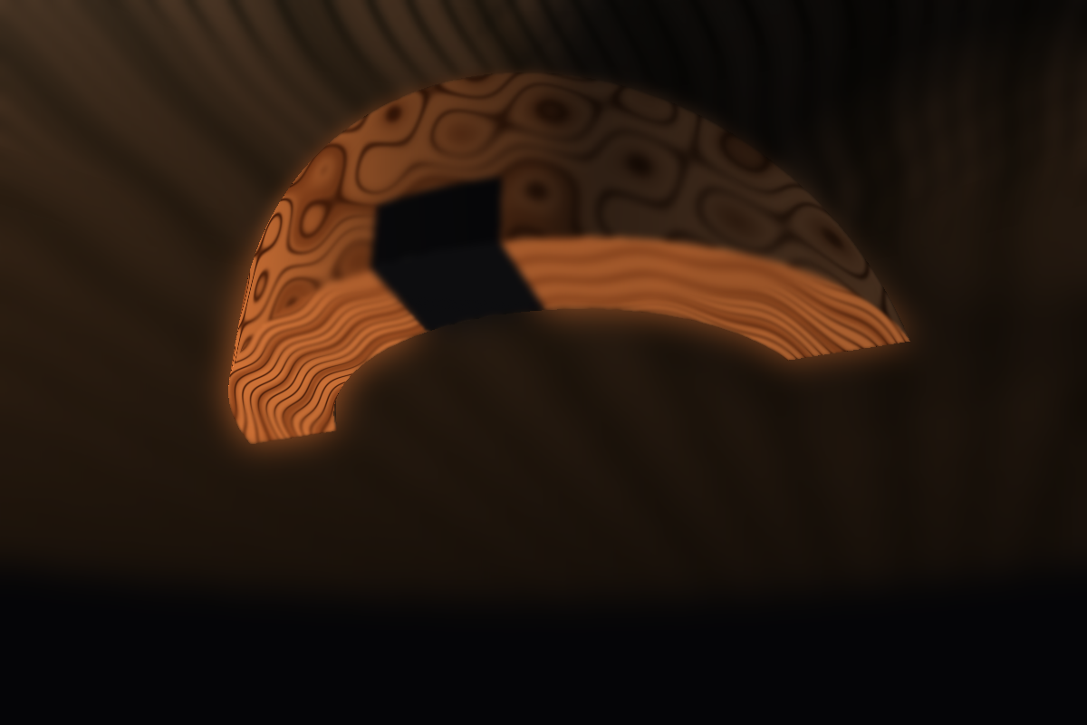
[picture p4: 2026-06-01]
images/macro/utaguchi-bevel.png

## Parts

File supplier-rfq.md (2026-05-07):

# Shakuhachi Supplier RFQ — SHK-D4-P1 + family setup

## Project context

Solo luthier project to build a small family of solid-billet hardwood shakuhachi (1.8-shaku D4 first, S/M/L members later). This RFQ covers the bench-build phase: tonewood, deep-bore drilling tooling, validation hardware, finish, and an optional inlay block. Quantity is small (1–3 of each item); we will scale orders for the full eight-key family if the first prototype validates the workflow.

## Items

### Tonewood

- **3× hardwood turning blanks**, 1.000 × 1.000 × 24.000 in, quarter-sawn, kiln-dried < 8 % MC.
  - Primary preference: **cherry** (Prunus serotina) for SHK-D4-P1.
  - Backup species, 1 each: **hard maple** (Acer saccharum) and **black walnut** (Juglans nigra).
  - Quarter-sawn matters; we will be drilling a 21+ in deep bore and want minimal anisotropic wander.
  - No knots, internal checks, or inclusions in the bore region (centerline ± 0.4 in).
  - Acceptable substitutes if cherry is short: persimmon (Diospyros virginiana), American holly, hard pear.

### Deep-bore drilling tooling

- **3/8 in brad-point bit**, 6 in flute length, 1/2 in shank for Jacobs chuck.
- **Aircraft-extension drill set 1/2 in / 5/8 in / 3/4 in** in 6–8 in flute lengths, HSS, brad-point preferred.
- **20 mm straight-flute reamer**, 24 in OAL, HSS, H7 tolerance (target final bore ID 0.787 +0.000 / +0.0008 in).

### Inlay block (optional)

- **1× water buffalo horn block**, ~0.5 × 1.0 × 1.0 in solid. Verify CITES status (water buffalo *Bubalus bubalis* is **not** listed and is freely tradable; black-buffalo *Synceros caffer* is regulated). If unavailable, substitute **lignum vitae** or **African blackwood** (Dalbergia melanoxylon — note CITES Appendix II listing for this substitute, requires CITES re-export documentation).

### Validation hardware

- **1× chromatic tuner with cents readout** (Korg OT-120 or equivalent), ≤ 1 cent resolution, condenser-mic input.
- **1× thermometer / hygrometer**, ±0.5 °F / ±2 % RH, lab-grade.
- **1× bore-gauge or pin-gauge set**, 0.500–0.875 in by 0.001 in increments (or three-point internal mic). Existing tooling preferred; this line is for documentation.

### Finish

- **1× walnut oil 8 oz**, raw, no metallic dryers, food-safe.
- **1× carnauba wax 4 oz**, pure or mostly-pure carnauba paste.

### Hardware for fixtures (one-time)

- **2 ft of 1.5 × 1.5 × 1/8 in cold-rolled steel angle.**
- **2× 6 in lengths of 3/8-16 zinc-plated threaded rod**, with hex nuts and washers.

## Delivery

- All items deliver to Tony Koop's shop. No specific deadline; SHK-D4-P1 cuts when materials and tooling are in hand.
- Itemize cost per line; combined shipping welcome.
- Backorders: please flag any item with > 14-day lead time so we can switch to a substitute supplier.

## Notes for the supplier

- This is a research/portfolio prototype, not a commercial production run. Order quantity is small but we expect repeat orders for siblings (Eb4 / E4 / F4 / G4 / A4 / B4) if SHK-D4-P1 validates.
- Quarter-sawn is a hard requirement on tonewood; flat-sawn will deflect under the deep-bore drilling step and we'll have to scrap and re-order.
- For the reamer: a slightly oversize (0.788–0.790 in) reamer is acceptable since acoustic predictions can be re-fit to the larger bore. A noticeably *under*-size reamer (< 0.785 in) is not acceptable and will require re-cutting the supplier order.

## Decision criteria

We will pick the supplier offering:

1. Quarter-sawn cherry that meets the dimensional spec.
2. The 20 mm reamer at 24 in OAL (the limiting tooling item).
3. Reasonable lead time (< 10 business days on the critical-path items).

If a single supplier cannot fill all of the above, we will split the order across two suppliers.

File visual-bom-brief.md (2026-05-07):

# Visual BOM Brief — SHK-D4-P1

A single-sheet visual bill of materials laid out as a printed plate. Used for shop reference, capstone-deck "BOM" slide, and the build-log site's BOM section.

## Sheet layout

- A3 landscape (16.5 × 11.7 in), printable at 100% scale on a tabloid printer.
- Title block: top, full-width band with project name, drawing rev, date.
- Body: 4 columns × 4 rows of part cells; 1 hero photo cell spanning two cells in the upper-left.

## Cells (4 × 4 grid, by row)

### Row 1 (hero + critical-path tooling)

- **Hero (cells A1+B1+A2+B2, 2×2):** finished SHK-D4-P1 instrument, oblique view, 35° from horizontal. Background neutral. Caption: *"Shakuhachi SHK-D4-P1 — solid cherry, 1.8-shaku D4, 21.5 in OAL."*
- **C1: Hardwood blank (SHK-BOM-001)** — photo of unmilled 1×1×24 in cherry blank with end-grain visible. Caption: *"Quarter-sawn cherry, kiln-dried < 8% MC. 3 blanks ordered."*
- **D1: Long reamer (SHK-BOM-005)** — photo of the 20 mm × 24 in reamer flat on white seamless. Caption: *"20 mm straight-flute reamer, 24 in OAL. Final-pass bore tool."*

### Row 2

- **C2: Pilot + step-up bits (SHK-BOM-003 + 004)** — group photo. Caption: *"3/8 → 1/2 → 5/8 → 3/4 in long-shank bits. Stepped-up bore in 4 mm increments."*
- **D2: Tailstock vise (SHK-BOM-006)** — staged photo of the welded fixture on the lathe tailstock. Caption: *"Custom carrier — square blank gripped, MT2-mounted. See instrument-maker#84."*

### Row 3

- **A3: Tone-hole jig (SHK-BOM-007)** — drill-press jig photo. Caption: *"V-cradle + index pin, drills front and back holes from the same axis."*
- **B3: Utaguchi gauge (SHK-BOM-009)** — printed-and-glued 32° gauge resting on a sample notch. Caption: *"Reference angle: 32° inner bevel. Printed at 1:1, glued to acrylic."*
- **C3: Diamond files (SHK-BOM-008)** — round + flat 6-in pair on white. Caption: *"Hole-tuning toolkit. File-open in 0.5 mm steps."*
- **D3: Chromatic tuner (SHK-BOM-010)** — Korg OT-120 face-on. Caption: *"Korg OT-120 — ≤1 cent resolution. Already in shop."*

### Row 4

- **A4: Walnut oil + carnauba (SHK-BOM-013 + 014)** — bottle + tin grouped. Caption: *"Tried & True walnut oil bore + outside; carnauba wax outside only."*
- **B4: Buffalo horn block (SHK-BOM-002)** — single photo if pursued; else replace cell with empty box and caption *"Optional inlay — skipped for SHK-D4-P1."*
- **C4: Brad-point hole bits (SHK-CUT-004 et al.)** — 7 mm brad-point drill close-up. Caption: *"Tone-hole drill: 7 mm brad-point, undersize. File to final size."*
- **D4: Pin gauge / bore gauge (SHK-BOM-011)** — measurement tools on white. Caption: *"Bore-ovalization check: 3 readings 120° apart at each station."*

## Photo treatment

- Lighting: soft side light, 45°. White or neutral-grey background.
- Color: shoot ColorChecker reference with first photo of the day; correct in post.
- File format: PNG for visual BOM cells (preserves edges); JPG for hero.
- Resolution: 1200 × 1200 px minimum per cell (4 in @ 300 dpi).

## Cross-reference table

| Cell | BOM ID(s) | Drawing reference |
| ---- | --- | --- |
| A1-B2 | SHK-D4-P1 (assembly) | drawings/SHK-D4-P1-overall.svg |
| C1 | SHK-BOM-001 | drawings/SHK-D4-P1-blank.svg |
| D1 | SHK-BOM-005 | assembly-manual.md § Step 5 |
| C2 | SHK-BOM-003 + 004 | assembly-manual.md § Step 4–5 |
| D2 | SHK-BOM-006 | drawings/SHK-fixture-vise.svg |
| A3 | SHK-BOM-007 | drawings/SHK-fixture-hole-jig.svg|
| B3 | SHK-BOM-009 | drawings/SHK-D4-P1-utaguchi.svg  |
| C3 | SHK-BOM-008 | validation.csv per-hole rows |
| D3 | SHK-BOM-010 | validation.csv all measure rows  |
| A4 | SHK-BOM-013 + 014 | assembly-manual.md § Step 12 |
| B4 | SHK-BOM-002 (optional)| drawings/SHK-D4-P1-utaguchi.svg  |
| C4 | (cut-list) | cut-list.csv SHK-CUT-004…008 |
| D4 | SHK-BOM-011 | validation.csv post-bore rows |

## Total pictured cost

Sum of `bom.csv estimated_cost` for items pictured: ~430 USD (excluding the optional buffalo-horn inlay and mortising chisels). Update this number in the visual BOM bottom-right "Total" cell as orders confirm.

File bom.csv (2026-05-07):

item_id | subsystem | item | qty | unit | material_spec | make_buy | drawing_ref | supplier | estimated_cost | notes
SHK-BOM-001 | Body | Hardwood blank 1in x 1in x 24in | 3 | blanks | Quarter-sawn, kiln-dried; cherry primary, hard maple + black walnut backups | Buy | drawings/SHK-D4-P1-blank.svg | Bell Forest Products | 28.00 USD | Three blanks: one for SHK-D4-P1 + two for utaguchi/bore practice runs.
SHK-BOM-002 | Body | Optional inlay block | 1 | piece | Buffalo horn 0.5in x 0.787in x 0.060in OR lignum vitae alternative | Buy | drawings/SHK-D4-P1-utaguchi.svg | Roy's Woodturning Tools | 12.00 USD | Mortised flush at utaguchi top edge. Skip for first prototype if schedule pressed.
SHK-BOM-003 | Tooling | 3/8 in pilot brad-point bit | 1 | bit | 6+ in OAL, MT2 Jacobs-chuck-mounted | Buy | assembly-manual.md | Lee Valley | 16.00 USD | Pilot pass for headstock-driven deep-bore drilling.
SHK-BOM-004 | Tooling | Step-up drill set 1/2 in / 5/8 in / 3/4 in long-shank | 1 | set | 6-8 in OAL each; spade or aircraft-extension | Buy | assembly-manual.md | Grizzly | 42.00 USD | Step bores in 4 mm diameter increments to limit wander.
SHK-BOM-005 | Tooling | Final-bore reamer 0.787 in (20 mm) | 1 | reamer | Straight-flute reamer, 24 in OAL | Buy | assembly-manual.md | Travers Tool | 68.00 USD | Or substitute step-down endmill in collet chuck.
SHK-BOM-006 | Tooling | Tailstock vise / square-stock carrier | 1 | fixture | Custom: 6 in jaw with V-block + side clamps; aligned to MT2 spindle axis | Make | drawings/SHK-fixture-vise.svg | — | 35.00 USD | Build from steel angle + threaded rod. See instrument-maker#84.
SHK-BOM-007 | Tooling | Tone-hole drill jig | 1 | fixture | Drill-press jig: V-cradle + index pin + indexed sliding stop | Make | drawings/SHK-fixture-hole-jig.svg | — | 15.00 USD | Indexes off the bore axis. Allows re-drilling at consistent radial angle.
SHK-BOM-008 | Tooling | Diamond hand files (round + flat) 1/2 round 6 in | 1 | set | Fine grit 600+; for bisque-style hole tuning | Buy | validation.csv | Lee Valley | 22.00 USD | Open holes in 0.5 mm steps; use round file for hole, flat for utaguchi bevel touch-up.
SHK-BOM-009 | Tooling | 32-deg utaguchi gauge | 1 | gauge | Aluminum or printed; references angle off bore axis | Make | drawings/SHK-D4-P1-utaguchi.svg | — | 4.00 USD | Print + glue to acrylic.
SHK-BOM-010 | Validation | Chromatic tuner with cents readout | 1 | unit | Korg OT-120 or equivalent; resolution >= 1 cent | Buy | validation.csv | Sweetwater | 89.00 USD | Already in shop; line item documents the validation tooling.
SHK-BOM-011 | Validation | Bore-gauge / pin-gauge set | 1 | set | 0.500 in to 0.875 in by 0.001 in; or three-point internal mic | Use | validation.csv | — | 0.00 USD | Existing shop tooling.
SHK-BOM-012 | Validation | Thermometer / hygrometer | 1 | unit | +/- 0.5 deg F, +/- 2 percent RH | Use | validation.csv | — | 0.00 USD | Existing shop tooling. Critical because shakuhachi pitch shifts ~3 cents/deg C.
SHK-BOM-013 | Finish | Walnut oil (food-safe) | 1 | 8 oz bottle | Tried & True or Mahoney's; raw walnut, unboiled | Buy | assembly-manual.md | Tried & True | 14.00 USD | Flooded inside the bore + outside; cures 3-5 days.
SHK-BOM-014 | Finish | Carnauba wax | 1 | 4 oz tin | Pure carnauba flakes or paste; outside-only application | Buy | assembly-manual.md | Constantine's | 11.00 USD | Outside finish only; do not put wax inside the bore (changes acoustic damping).
SHK-BOM-015 | Documentation | A4 paper wrap template | 1 | sheet | Printed hole-position template, lengthwise; CMYK black-on-white | Make | drawings/SHK-D4-P1-hole-layout.svg | — | 0.50 USD | Printed at 100% scale; wraps the cylindrical body.
SHK-BOM-016 | Optional | Buffalo-horn mortising chisel set | 1 | set | 3 mm + 6 mm + 12 mm bench chisels; for utaguchi inlay seat | Buy | drawings/SHK-D4-P1-utaguchi.svg | Hida Tool | 68.00 USD | Skip if SHK-BOM-002 inlay is omitted on first prototype.

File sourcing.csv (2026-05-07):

item_id | supplier | product | required_spec | search_terms | unit_price_usd | lead_time_days | sku_or_url | verified_on | notes
SHK-SRC-001 | Bell Forest Products | Cherry turning blanks | 1 in x 1 in x 24 in; quarter-sawn; kiln-dried < 8% MC | cherry turning blank 24 inch quartersawn | 9.50 | 5 | bellforestproducts.com/cherry-turning-blanks | TBD | Buy 3 to allow practice bores. Quarter-sawn flutters less under deep drilling than flat-sawn.
SHK-SRC-002 | Bell Forest Products | Hard maple turning blanks | 1 in x 1 in x 24 in; quarter-sawn | hard maple turning blank 24 inch quartersawn | 8.75 | 5 | bellforestproducts.com/hard-maple | TBD | Backup wood for SHK-D4-P2 if cherry tears out at hole walls.
SHK-SRC-003 | Bell Forest Products | Black walnut turning blanks | 1 in x 1 in x 24 in | black walnut turning blank 24 inch | 10.20 | 5 | bellforestproducts.com/black-walnut | TBD | Lower density alternative — softer voice expected.
SHK-SRC-004 | Roy's Woodturning Tools | Buffalo horn block | 0.5 in x 1 in x 1 in solid block | buffalo horn turning block luthier | 11.00 | 7 | royswoodturning.com | TBD | For utaguchi inlay if pursued. Verify CITES status (water buffalo not listed).
SHK-SRC-005 | Lee Valley | Brad-point drill long-shank 3/8 in | 6 in flute length, 1/2 in shank | brad point bit long shank 3/8 inch | 15.95 | 3 | leevalley.com/05M2110 | TBD | Pilot bore for deep-drilling sequence.
SHK-SRC-006 | Grizzly Industrial | Aircraft-extension drill set 1/2-3/4 in | 6 in flute lengths; HSS | aircraft extension drill set hss long | 42.00 | 5 | grizzly.com/products/aircraft-extension-drill-bit-set | TBD | Used for stepping up the bore in 4 mm increments.
SHK-SRC-007 | Travers Tool | Reamer 20 mm straight-flute | 24 in OAL; HSS; H7 tolerance | reamer 20mm straight flute extra long | 68.50 | 10 | travers.com/reamer-20mm-long | TBD | Final-pass to 0.787 in. Verify ID before ordering — H7 0.787 +0.000 / +0.0008 in.
SHK-SRC-008 | Lee Valley | Diamond hand files 6 in 600 grit | Round + flat profile pair | diamond file luthier 600 grit fine | 21.95 | 3 | leevalley.com/diamond-hand-files | TBD | Bisque-style hole tuning.
SHK-SRC-009 | Sweetwater | Korg OT-120 chromatic tuner | +/- 1 cent resolution; condenser-mic input | korg ot 120 chromatic tuner orchestral | 89.00 | 2 | sweetwater.com/store/detail/OT120 | TBD | Already in Tony's shop; entry documents validation tooling.
SHK-SRC-010 | Tried & True | Original walnut oil 8 oz | Raw walnut oil, no metallic dryers; food-safe | tried true original walnut oil 8oz | 13.95 | 4 | triedandtruewoodfinish.com | TBD | Inside bore + outside finish.
SHK-SRC-011 | Constantine's | Carnauba wax tin 4 oz | Pure carnauba paste; outside-only | constantines pure carnauba wax | 10.95 | 4 | constantines.com | TBD | Outside finish — do not apply inside the bore.
SHK-SRC-012 | Hida Tool | Japanese mortising chisels 3-6-12 mm | For utaguchi inlay seat (optional) | hida tool japanese mortising chisel set | 68.00 | 7 | hidatool.com | TBD | Skip if first prototype omits inlay.
SHK-SRC-013 | McMaster-Carr | Steel angle 1.5 in x 1.5 in x 1/8 in | Cold-rolled, 12 in length | steel angle 1.5 inch cold rolled 12 inch | 7.40 | 2 | mcmaster.com/8910K156 | TBD | Stock for the tailstock vise / square-stock carrier fixture.
SHK-SRC-014 | McMaster-Carr | Threaded rod 3/8-16 + nuts | 6 in length pair; zinc-plated | mcmaster 3/8-16 threaded rod 6 inch | 3.80 | 2 | mcmaster.com/98031A015 | TBD | Vise clamping screws.

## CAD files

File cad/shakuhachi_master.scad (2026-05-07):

// shakuhachi_master.scad
// Parametric OpenSCAD master for SHK-D4-P1 (1.8-shaku D4 solid-billet)
// Sister: tonykoop/shakuhachi
// Skill:  instrument-maker-v4
// Date:   2026-05-07
//
// Render notes:
//   - $fn = 96 for production renders; reduce to 24 for live preview.
//   - Outputs an STL representation of the *finished* instrument geometry.
//     The bore is subtracted; the utaguchi notch is subtracted; tone holes
//     are subtracted at their predicted first-pass positions.
//   - This is a CAD reference, NOT a CNC toolpath. The actual build is
//     bore-first via the headstock-driven deep-bore drilling technique
//     (instrument-maker#84) followed by an outside turn.
//   - Tone-hole positions come from the open-pipe model in design.md.
//     Final hole sizes/positions are determined empirically via
//     bisque-style filing.

// ===== Parameters =====

// Acoustic
fund_freq        = 293.665;     // D4 fundamental, Hz
c_air            = 13552;       // Speed of sound at 68 F, in/s
bore_id          = 0.787;       // Final bore diameter, in (= 20 mm)
delta_foot       = 0.6 * (bore_id / 2);
delta_utaguchi   = 1.7 * (bore_id / 2);   // empirical; refine after measurement

// Geometry
od               = 1.10;
length_phys      = c_air / (2 * fund_freq) - delta_foot - delta_utaguchi;  // ~21.50

// Utaguchi
utag_width       = bore_id;
utag_depth       = 0.315;
utag_angle_deg   = 32;

// Tone holes — first-pass acoustic stations from foot
hole_diam        = 0.276;     // 7 mm starting size, file open during tuning
function hole_d_from_foot(semis) =
    (c_air / (2 * fund_freq)) * (fund_freq / (fund_freq * pow(2, semis/12)));
hole1_d_foot     = hole_d_from_foot(3);   // Tsu / F4   ~19.40
hole2_d_foot     = hole_d_from_foot(5);   // Re  / G4   ~17.29
hole3_d_foot     = hole_d_from_foot(7);   // Chi / A4   ~15.40
hole4_d_foot     = hole_d_from_foot(10);  // Ri  / C5   ~12.95
thumb_d_foot     = hole_d_from_foot(12);  // Ro' / D5   ~11.54

$fn = 64;

// ===== Modules =====

module body_blank() {
    // Origin: centered on bore axis, foot at z=0, utaguchi at z=length_phys.
    cylinder(h = length_phys, d = od, $fn = 96);
}

module bore() {
    translate([0, 0, -0.05])
        cylinder(h = length_phys + 0.10, d = bore_id, $fn = 96);
}

module utaguchi_notch() {
    // Notch is cut into the +Y face at the top end (utaguchi side).
    // It removes a wedge whose inner-bevel angle is utag_angle_deg
    // measured from the bore axis.
    top_z = length_phys;
    notch_h = utag_depth;
    inner_bevel = utag_angle_deg;

    translate([0, od/2 - 0.001, top_z - notch_h])
        rotate([0, 0, 0])
        // Wedge: a triangular prism cut into the wall.
        difference() {
            translate([-utag_width/2, 0, 0])
                cube([utag_width, od, notch_h + 0.05]);

            // Inner-bevel wall — the angled face that defines edge tone.
            translate([-utag_width/2 - 0.05, -0.05, notch_h])
                rotate([90 - inner_bevel, 0, 0])
                cube([utag_width + 0.10, od + 0.10, notch_h * 2]);
        }
}

module tone_hole(d_from_foot, on_back = false) {
    // Drill a Ø hole_diam through the wall at distance d_from_foot from the
    // foot, centered on the front (+Y) face by default, or on the back (-Y)
    // for the thumb hole.
    y_dir = on_back ? -1 : 1;
    translate([0, y_dir * (od/2 + 0.10), d_from_foot])
        rotate([90, 0, 0])
        cylinder(h = od + 0.20, d = hole_diam, $fn = 32);
}

module shakuhachi_d4_p1() {
    difference() {
        body_blank();
        bore();
        utaguchi_notch();
        tone_hole(hole1_d_foot);
        tone_hole(hole2_d_foot);
        tone_hole(hole3_d_foot);
        tone_hole(hole4_d_foot);
        tone_hole(thumb_d_foot, on_back = true);
    }
}

// ===== Render =====
shakuhachi_d4_p1();

// ----- Console echo for design table cross-check -----
echo(str("L_physical = ", length_phys, " in"));
echo(str("delta_foot = ", delta_foot, " in"));
echo(str("delta_utaguchi = ", delta_utaguchi, " in"));
echo(str("hole1 (Tsu / F4) d_from_foot = ", hole1_d_foot, " in"));
echo(str("hole2 (Re / G4)  d_from_foot = ", hole2_d_foot, " in"));
echo(str("hole3 (Chi / A4) d_from_foot = ", hole3_d_foot, " in"));
echo(str("hole4 (Ri / C5)  d_from_foot = ", hole4_d_foot, " in"));
echo(str("thumb (Ro' / D5) d_from_foot = ", thumb_d_foot, " in"));

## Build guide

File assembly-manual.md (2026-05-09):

# Shakuhachi Assembly Manual — SHK-D4-P1 (1.8-shaku D4 prototype)

This manual builds the first prototype documented in `design.md` and the rows of `bom.csv` / `cut-list.csv` / `validation.csv`. It assumes a North American luthier shop with a wood-lathe (MT2 or MT3 spindle), drill press, bandsaw, and standard hand tools — *not* a traditional Japanese bamboo workshop.

> **Cultural note:** traditional shakuhachi are built from madake bamboo with urushi-lined bores. This packet documents a Western-shop solid-billet hardwood adaptation. Where it diverges from tradition (solid billet, straight bore, oil finish, no urushi), it is documented as such. Apprenticeship under a *seibei* (traditional maker) is the right path if the goal is a tradition-faithful instrument; this packet is a parametric study tool.

## Bill of materials reference

See `bom.csv` (16 line items). Confirm SHK-BOM-001 through 008 + 010 + 013 are on hand before starting Step 1. SHK-BOM-002 (buffalo-horn inlay) and SHK-BOM-016 (mortising chisels) are optional for the first prototype.

## Step 0 — Read first

1. Read `design.md` § Governing Model and § Empirical-correction guard. The shakuhachi-specific utaguchi end correction is the source of most prediction error; understand what it is before measuring.
2. Read `risks.md` end-to-end. Each risk has a verification test attached.
3. Read [`tonykoop/instrument-maker#84`](https://github.com/tonykoop/instrument-maker/issues/84) and the technique reference at `references/techniques/headstock-driven-deep-bore-drilling.md`. The deep-bore step is the single highest-risk operation.

## Step 1 — Mill blanks

1. Select three quarter-sawn cherry blanks at least `1.00 x 1.00 x 24.50 in`, or mill them from longer 6/4 stock. One blank is for SHK-D4-P1; two are for bore / utaguchi practice and recovery. Inspect for runout, knots, and internal checks.
2. Mill each blank to `1.000 x 1.000 x 24.000 in` (±0.005 in). Quarter-sawing matters for deep-bore drilling: tangential expansion is anisotropic, and quarter-sawn blanks wander less under heat from drill chips.
3. Mark each blank with face / edge / end orientation in pencil.

## Step 2 — Center-mark and cross-mark

1. Find the center of each end face with a center-finder. Punch with an awl.
2. Use a marking gauge to draw the bore-axis line on two adjacent faces of the blank, end to end. This line is the visual reference for jig alignment.
3. Choose the face that will become the **front** (utaguchi side) and mark "F" on a non-machined surface. The utaguchi notch and four front holes go on this face; the thumb hole goes on the opposite face.

## Step 3 — Build the tailstock vise (one-time)

If `SHK-fixture-vise` has already been built, skip to Step 4. Otherwise:

1. Cut steel angle (SHK-SRC-013) to two 6 in pieces; weld into a U-channel that bolts to a Morse-tapered shank that fits the lathe tailstock.
2. Drill / tap two 3/8-16 holes for the side clamp screws. The square blank rests in the V of the channel; the screws push it against the V from above.
3. Indicate the V-channel against the spindle axis using a test indicator. Adjust the Morse-taper shank until centerline runout is < 0.005 in.

> Reference: `references/techniques/headstock-driven-deep-bore-drilling.md` § Fixture Requirements.

## Step 4 — Scrap-stock validation pass (mandatory)

1. Mount the 3/8 in pilot bit (SHK-BOM-003) in the headstock Jacobs chuck. Indicate runout < 0.003 in.
2. Clamp a straight pine or poplar scrap blank at least 24 in long in the tailstock vise. Tighten side clamps; the blank must not rotate under finger pressure.
3. Bring the blank up to the bit; verify the punch mark on the end face tracks the spindle axis.
4. Pilot-bore 6 in into the scrap with the lathe at ~1500 rpm. Peck depth ≤ 1 in; retract every peck to clear chips.
5. Withdraw blank; measure bore axis offset at 6 in. Target: ≤ 0.020 in offset. If exceeded, re-indicate the fixture and repeat.
6. Continue scrap pilot-bore to 12 in, 18 in. Record offsets in `validation.csv` rows `scrap-validation`. If offsets fall outside spec, **stop** and reset; do not proceed to production cherry.

## Step 5 — Production deep-bore (the long one)

> This step is the highest-risk operation in the build. Expect 90 minutes for a full bore + measurements; do not rush.

1. Clamp a cherry blank (SHK-BOM-001) in the tailstock vise. Re-verify centering.
2. Lathe at ~1200 rpm with the 3/8 in pilot. Peck 1 in deep, retract, advance, repeat until pilot bore is 23 in (full length minus 1 in clearance at the foot end).
3. Step up: 1/2 in bit → 5/8 in → 3/4 in (SHK-BOM-004). Each step pecks the full 23 in. Slow the lathe to ~800 rpm for the larger bits; long bits whip at higher rpm.
4. Final reamer pass with the 0.787 in / 20 mm reamer (SHK-BOM-005) at ~600 rpm with cutting oil. Single advance, no peck — reamers cut on the side and chatter if reciprocated.
5. Withdraw, blow chips out of the bore, and measure ID at foot, mid (10.75 in), and top stations using the bore gauge. Record `validation.csv` `post-bore` rows.
6. **Halt criterion:** ovalization > 0.005 in or any station outside 0.787 ±0.005 in → reject blank; pull the next prepared cherry blank.

## Step 6 — Turn outside

1. Cut two pieces of dowel (or two pin-centers) sized to slip-fit the bore. Insert one into each end of the bored blank.
2. Mount the blank between centers, *registering off the bore* — this is why the bore is drilled first. The bore axis becomes the lathe rotation axis and any wander stays inside the wall, not visible on the outside.
3. Rough-turn to ~1.20 in OD with a roughing gouge.
4. Finish-turn to 1.10 in OD with a spindle gouge + skew chisel. Keep the profile straight (no decorative beads on the prototype). Final OD ±0.010 in.
5. Sand 220 → 320 → 400 grit. Wipe with mineral spirits to check for tearout.
6. Part off at 21.5 in finished length, leaving ~0.5 in waste. Square the foot end on the lathe with a parting tool + sandpaper face.

## Step 7 — Tone-hole layout and undersized drilling

1. Print the hole-position template (`drawings/SHK-D4-P1-hole-layout.svg`) at 100% scale on A3 (or two A4 sheets joined). Verify printed length = 21.5 in.
2. Wrap the template around the cylindrical body, aligning the foot mark with the foot end of the body. Tape in place.
3. Punch each tone-hole center through the template with a sharp awl. Remove template.
4. Build / dust off the tone-hole jig (`SHK-fixture-hole-jig`): a V-cradle with an index pin that registers off the back of the body (180° from front holes), and an indexed sliding stop that moves the body along the V to each hole position.
5. Mount jig on drill press. Mount 7 mm brad-point in chuck. Indicate so bit is centered on the V-cradle radius.
6. Drill each hole one at a time, advancing the body along the index. Drill **undersized** to 0.276 in (7 mm). Do not enlarge with the drill — leave room for filing during tuning.
7. Rotate jig 180° (or rotate body 180° in jig) and drill the thumb hole at 11.54 in from foot, on the back face.

## Step 8 — Cut the utaguchi

1. Mark the utaguchi notch on the top end of the body: width 0.787 in (= bore ID), depth 0.315 in.
2. Bandsaw the rough notch — straight cuts only, leaving 0.030 in of finishing stock all around the layout line.
3. Clamp body horizontally in a padded vise. Use a 1/2 in bench chisel to pare the inner bevel to a 32° angle. Reference the angle against a printed-and-glued utaguchi gauge (`SHK-BOM-009`).
4. File the inner bevel flat with a fine mill-bastard file. The outer-edge profile gets a 0.020-0.030 in round-over with a fine file.
5. **Do not over-shape on the first cut.** The next step measures fundamental pitch, and you can always deepen / re-angle the notch — you cannot un-cut wood.

## Step 9 — Bisque-style tuning (post-utaguchi)

1. Block all five tone holes with painter's tape (cleanly, edges flush with bore).
2. Blow Ro (fundamental). Use the chromatic tuner; record cents error vs `f₀ = 293.665 Hz` in `validation.csv`.
3. Sounding sharp (> +25 cents): deepen the utaguchi notch in 0.020 in increments. Each 0.010 in of depth ≈ 5–8 cents flatter.
4. Sounding flat (< −25 cents): shorten the foot end on the lathe by 0.05 in increments. Each 0.10 in of length ≈ 13 cents sharper.
5. Re-measure. Iterate until ±25 cents pre-tuning band is hit. Record final fundamental in `validation.csv`.

## Step 10 — Per-hole tuning

1. Open hole 1 (Tsu / F4). Close all others with tape. Blow; record cents error.
2. If hole 1 sounds flat (< −15 cents), file the hole open in 0.5 mm increments using the round diamond file (SHK-BOM-008). Each 0.5 mm step ≈ 6–10 cents sharper. Record after each step.
3. Stop when within ±10 cents.
4. Repeat for holes 2, 3, 4, and the thumb hole — *one at a time*, with all others taped closed.
5. After all holes tune, record the full fingering progression Ro → Tsu → Re → Chi → Ri → Ro′ as a single connected pass. Cross-hole interactions can shift earlier-tuned holes; if the progression sits inside ±15 cents end to end, accept; otherwise re-file the worst offender 0.2 mm and re-measure.

## Step 11 — Octave check

1. Block all holes. Overblow Ro at the player's stronger jet — Ro′ should sound at ~587.33 Hz.
2. Record octave error in `validation.csv` row `octave`.
3. **Octave error > 25 cents** = bore-axis or utaguchi geometry problem; do **not** try to tone-hole-tune around it. Re-shape the utaguchi or accept the prototype as a study artifact for SHK-D4-P2.

## Step 12 — Finish

1. Flood the bore with walnut oil (SHK-BOM-013). Stand vertically, foot up, on a paper towel; let oil drain through. Wipe outside with same oil and a lint-free cloth.
2. Cure 3–5 days, depending on RH. Walnut oil cures by oxidation; warm dry air helps, plastic-bag storage hurts.
3. After cure: buff outside only with carnauba wax (SHK-BOM-014). Do **not** wax the bore — wax film changes acoustic damping.
4. Re-tune (Step 9–10) — finish often shifts pitch 3–8 cents flatter.

## Step 13 — Document

1. Photograph per `photo-shotlist.md`.
2. Record final measurements (one row per fingering) in `validation.csv` and run:

   ```bash
   python3 <instrument-maker-v4-install>/scripts/record_measurement.py \
     --packet . \
     --note-id Ro \
     --measured-hz <measured> \
     --tuner "Korg OT-120" \
     --environment "shop, <T>F, <RH>% RH"
   ```

3. Replace `<instrument-maker-v4-install>` with the local install path for the v4 skill/scripts bundle. The record-measurement script updates the per-family corrections database. Future packets in the shakuhachi family (SHK-Eb4-001 et al.) will read the updated `δ_utaguchi` correction automatically.

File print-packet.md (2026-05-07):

# Shakuhachi SHK-D4-P1 — Printable Shop Packet

**Project:** Shakuhachi (SHK-D4-P1)
**Date:** 2026-05-07
**Driver:** Tony Koop
**Skill:** instrument-maker-v4

---

## Cover / summary

A single-instrument build packet for **SHK-D4-P1** — a 1.8-shaku D4 solid-cherry shakuhachi prototype. Open-pipe acoustics; bore drilled with the headstock-driven deep-bore drilling technique on the lathe. Hand-cut utaguchi. Five tone holes (4 front + 1 thumb), tuned to Kinko-ryū intervals.

---

## Quick start (shop reference)

| Step | Operation | Time | Page |
| ---- | --- | --- | ---- |
| 1 | Mill blanks (1×1×24 cherry) | 30 min | §B |
| 2 | Build tailstock vise (1-time)  | 90 min | §C |
| 3 | Pine-scrap validation pass | 45 min | §D |
| 4 | Production deep-bore | 90 min | §D |
| 5 | Outside turn between centers | 60 min | §E |
| 6 | Tone-hole layout + drill 7 mm  | 45 min | §F |
| 7 | Cut + file utaguchi | 60 min | §G |
| 8 | Bisque-style tuning | 90 min | §H |
| 9 | Walnut-oil + cure | 5 d | §I |
| 10 | Carnauba wax + final pass | 30 min | §I |

---

## File map

- `design.md` — governing model + design narrative
- `bom.csv` — 16-line bill of materials
- `sourcing.csv` — supplier list with verified-on column
- `cut-list.csv` — blank → finished part ops
- `validation.csv` — measurement plan + targets
- `assembly-manual.md` — 13-step shop manual (full detail)
- `risks.md` — red-team register; every risk has a test
- `drawings/` — 6 SVG drawings (overall + section + utaguchi + hole template + 2 fixtures)
- `cad/shakuhachi_master.scad` — OpenSCAD parametric master
- `wolfram-starter.wl` — Wolfram package for cents math + correction-refit
- `shakuhachi-design-table.xlsx` — 11-key parametric workbook
- `site/index.html` — public build log

---

## §A — Design intent

Solid-billet hardwood adaptation of the shakuhachi. Western luthier shop. 1.8-shaku D4 first; sized siblings later. Document the open-pipe acoustic model honestly so the first measurement drives a corrections database update. Not a tradition-faithful reproduction; respectful of Kinko-ryū / Tozan-ryū lineage.

---

## §B — Bill of materials

(extract — full table in `bom.csv`)

| ID | Item | Qty | Cost (USD) |
| --- | --- | --- | ---: |
| SHK-BOM-001 | Cherry blanks 1×1×24 in | 3 | 28.00 |
| SHK-BOM-003 | 3/8 in pilot brad-point bit | 1 | 16.00 |
| SHK-BOM-004 | Step-up drill set 1/2-3/4 in | 1 | 42.00 |
| SHK-BOM-005 | 20 mm reamer 24 in OAL | 1 | 68.00 |
| SHK-BOM-006 | Tailstock vise (build) | 1 | 35.00 |
| SHK-BOM-007 | Tone-hole drill jig (build) | 1 | 15.00 |
| SHK-BOM-008 | Diamond files round + flat | 1 | 22.00 |
| SHK-BOM-010 | Korg OT-120 chromatic tuner | 1 | 89.00 |
| SHK-BOM-013 | Walnut oil 8 oz | 1 | 14.00 |
| SHK-BOM-014 | Carnauba wax 4 oz | 1 | 11.00 |

**Total pictured: ~430 USD** excluding optional inlay block.

---

## §C — Sourcing list

Primary: Bell Forest Products (cherry), Travers Tool (reamer), Lee Valley (bits + files), Sweetwater (tuner), Tried & True (walnut oil), McMaster-Carr (vise hardware).

**Long-lead item:** 20 mm reamer (~10 days). Order first.

---

## §D — Cut list (extract)

(full table in `cut-list.csv`)

| Cut ID | Part | Operation |
| --- | --- | --- |
| SHK-CUT-001 | Cherry blank | Headstock-driven deep-bore + turn between centers |
| SHK-CUT-002 | Foot end face | Lathe parting + sandpaper face |
| SHK-CUT-003 | Utaguchi notch  | Bandsaw + chisel + file (32° inner bevel) |
| SHK-CUT-004…008 | Tone holes | Drill press w/ V-cradle jig; 7 mm brad-point undersize |

---

## §E — Drawing reference

| Drawing | Shows | Scale |
| --- | --- | ----- |
| SHK-D4-P1-overall.svg | Side elevation, full body, hole positions | 1:2 |
| SHK-D4-P1-bore-section.svg | Section A-A through bore axis | 1:2 |
| SHK-D4-P1-utaguchi.svg | Utaguchi notch geometry, 32° bevel | 4:1 |
| SHK-D4-P1-hole-layout.svg | Unwrapped cylinder paper-wrap template | 1:1 |
| SHK-D4-P1-blank.svg | Pre-bore square stock | 1:4 |
| SHK-fixture-vise.svg | Tailstock vise welded fixture | 1:2 |
| SHK-fixture-hole-jig.svg | Tone-hole drill-press V-cradle jig | 1:2 |

---

## §F — Assembly manual

See `assembly-manual.md` for the full 13-step shop manual. The steps are:

1. Read first (design.md, risks.md, instrument-maker#84)
2. Mill blanks
3. Center-mark + cross-mark
4. Build tailstock vise (one-time)
5. Scrap-stock validation pass (mandatory)
6. Production deep-bore (the long one)
7. Outside turn
8. Tone-hole layout + drill undersize
9. Cut utaguchi
10. Bisque-style tuning (post-utaguchi)
11. Per-hole tuning
12. Octave check
13. Finish + record

---

## §G — Validation / tuning sheet

(blanks for shop notes — see `validation.csv` for the full row set)

| Stage | Target | Measured | Pass / Fail | Notes |
| --- | --- | --- | --- | ----- |
| Bore wander @ 6 in | < 0.020 in | _____ | □ | |
| Bore wander @ 12 in | < 0.040 in | _____ | □ | |
| Bore wander @ 18 in | < 0.080 in | _____ | □ | |
| Bore ID @ foot | 0.787 ± 0.003 | _____ | □ | |
| Bore ID @ mid | 0.787 ± 0.005 | _____ | □ | |
| Bore ID @ top | 0.787 ± 0.005 | _____ | □ | |
| Wall @ hole-4 station  | ≥ 0.150 in (any quadrant) | _____ | □ | |
| Ro fundamental | 293.665 Hz ± 25 ¢ (pre-tune) | _____ | □ | |
| Ro fundamental | 293.665 Hz ± 10 ¢ (post-tune) | _____ | □ | |
| Tsu (F4) | 349.228 Hz ± 10 ¢ | _____ | □ | |
| Re (G4) | 391.995 Hz ± 10 ¢ | _____ | □ | |
| Chi (A4) | 440.000 Hz ± 10 ¢ | _____ | □ | |
| Ri (C5) | 523.251 Hz ± 10 ¢ | _____ | □ | |
| Thumb (D5) | 587.330 Hz ± 10 ¢ | _____ | □ | |
| Octave Ro → Ro′ | 587.330 Hz ± 25 ¢ | _____ | □ | |
| 30-day drift | < 5 cents at 68 °F | _____ | □ | |

Environment row (mandatory): Temp ____°F · RH ____% · tuner ____ · player ____

---

## §H — Supplier RFQ summary

See `supplier-rfq.md` for the full RFQ. Headlines: 3 quarter-sawn cherry blanks, 20 mm reamer at 24 in OAL, deep-bore drill set, validation hardware, oil + wax finish supplies, hardware for fixtures.

---

## §I — Visual BOM brief

A single-sheet (A3 landscape) plate with hero photo + tooling thumbnails + cost summary. See `visual-bom-brief.md` for the layout spec.

---

## §J — Appendix

- Cross-references: instrument-maker#84 (deep-bore drilling), tonykoop/flutes (NAF K2 — do not port), tonykoop/fujara (long open-pipe sister), tonykoop/transverse-flute (open-pipe packet template).
- Cultural framing: Western adaptation in respect for Kinko-ryū / Tozan-ryū lineage; not a tradition-faithful reproduction.
- Empirical loop: `record_measurement.py` updates per-family `δ_utaguchi` correction; sibling packets read forward.

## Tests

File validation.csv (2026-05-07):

build_id | instrument_id | stage | measurement | target_value | unit | tolerance | measured_value | environment | result | action
 | SHK-D4-P1 | scrap-validation | bore wander at 6 in | < 0.020 | in offset from spindle axis | Stop and reset jig if exceeded |  | Pine scrap blank; same fixture as production |  | Repeat scrap test before drilling production cherry. See instrument-maker#84 fallback plan.
 | SHK-D4-P1 | scrap-validation | bore wander at 12 in | < 0.040 | in offset from spindle axis | Stop and reset jig if exceeded |  | Pine scrap blank |  | Linear wander acceptable; sudden step indicates chip pack — retract more often.
 | SHK-D4-P1 | scrap-validation | bore wander at 18 in | < 0.080 | in offset from spindle axis | Stop and abort if exceeded |  | Pine scrap blank |  | Above 0.080 in offset, switch to staged drilling from both ends.
 | SHK-D4-P1 | post-bore | bore ID at foot | 0.787 | in | +/- 0.003 in |  | Bore gauge or pin gauge; 3 readings 120 deg apart |  | Reject if ovalization > 0.005 in.
 | SHK-D4-P1 | post-bore | bore ID at mid (10.75 in from foot) | 0.787 | in | +/- 0.005 in |  | Bore gauge |  | Mid-bore typically widest; reaming pass evens out.
 | SHK-D4-P1 | post-bore | bore ID at top (utaguchi) | 0.787 | in | +/- 0.005 in |  | Bore gauge |  | Top-of-bore matters acoustically — utaguchi is cut into this end.
 | SHK-D4-P1 | post-turn | wall thickness at hole 4 station (12.95 in from foot) | >= 0.150 | in | Minimum; abort if any quadrant < 0.140 |  | Calipers + bore reference |  | Verify before drilling tone holes.
 | SHK-D4-P1 | post-turn | OD at five stations | 1.10 | in | +/- 0.010 in |  | Calipers |  | Stations: foot, 5.5, 10.75, 16.0, 21.5 in.
 | SHK-D4-P1 | post-utaguchi | Ro fundamental (no holes covered? all holes covered) | 293.665 | Hz | +/- 25 cents pre-tuning, +/- 10 cents post-tuning |  | Korg OT-120; player TK; 68F, 45% RH; mic 6 in |  | File utaguchi or trim foot to bring fundamental within range.
 | SHK-D4-P1 | per-hole | Tsu (F4) hole 1 sounded freq | 349.228 | Hz | +/- 10 cents post-tuning |  | Tuner; player TK; environment per stage 3 |  | File hole open in 0.5 mm increments. Never enlarge with drill.
 | SHK-D4-P1 | per-hole | Re (G4) hole 2 sounded freq | 391.995 | Hz | +/- 10 cents post-tuning |  | Tuner; player TK
 | SHK-D4-P1 | per-hole | Chi (A4) hole 3 sounded freq | 440.000 | Hz | +/- 10 cents post-tuning |  | Tuner; player TK |  | Hole 3 typically needs the most filing.
 | SHK-D4-P1 | per-hole | Ri (C5) hole 4 sounded freq | 523.251 | Hz | +/- 10 cents post-tuning |  | Tuner; player TK
 | SHK-D4-P1 | per-hole | Thumb (D5) sounded freq | 587.330 | Hz | +/- 10 cents post-tuning |  | Tuner; player TK |  | Drilled on back; verify clean overblow before file-open.
 | SHK-D4-P1 | octave | Ro' (D5 by overblowing Ro fingering) | 587.330 | Hz | +/- 25 cents |  | Tuner; player TK |  | Octave error > 25 cents = bore taper / utaguchi geometry issue. Reshape, do not tone-hole-tune.
 | SHK-D4-P1 | 30-day-stability | Ro fundamental drift over 30 days | < 5 | cents drift | Daily measurements at constant 68F |  | Tuner; player TK; same time of day |  | Check pitch stability after oil cure + carnauba wax. If > 5 cents drift, reapply oil and re-cure.

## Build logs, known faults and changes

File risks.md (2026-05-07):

# Risk Register — SHK-D4-P1

Red-team pass over the design. Each risk is paired with a verification test that produces a row in `validation.csv` (or another concrete artifact). Risks are categorized: **acoustic**, **structural**, **manufacturing**, **ergonomic**, **supply**, **fit-and-finish**, **cultural**.

## Acoustic risks

### A1 — Utaguchi end-correction assumption is wrong

- **What:** `design.md` § Governing Model assumes `δ_utaguchi ≈ 1.5–2.0 · r_bore` based on back-fitting from the traditional 1.8-shaku ↔ D4 anchor. If the real correction is outside this band (e.g. 0.85·r if utaguchi behaves more like a flanged open end, or > 2.5·r at unusual bore geometries), SHK-D4-P1 will sound either too sharp or too flat by 15–40 cents and the entire family-spec table needs re-fitting.
- **Why it matters:** every other family member's predicted `L_physical` rolls forward from this single assumption. Bad correction → eight bad blanks.
- **Test:** post-utaguchi Stage 3 measurement of Ro fundamental in `validation.csv`. If pre-tuning fundamental is outside ±25 cents, run `record_measurement.py` to update `δ_utaguchi`; do not cut sibling blanks until the corrected value predicts SHK-Eb4-001 to within ±15 cents.
- **Mitigation:** the workflow only commits to one prototype before the correction is measured. Sibling blanks are queued, not cut.

### A2 — NAF K2 corrections accidentally applied

- **What:** Tony's K2 NAF corrections are baked into the workflow muscle-memory and into `flutes/`'s K2 columns. A future agent (or Tony in haste) could reflexively apply K2 to a shakuhachi row.
- **Why it matters:** K2 was derived from fipple-block + SAC NAFs. Shakuhachi has neither. K2 would over-correct hole positions by 3–10 mm and produce unplayable cents errors.
- **Test:** `design.md` § Empirical-correction guard explicitly calls this out. Workbook K2 columns for shakuhachi rows are intentionally blank. If a future packet generation adds K2 columns to shakuhachi, the validator should flag the cells.
- **Mitigation:** documented warning in `design.md`; per-instrument sister-repo registry entry includes "no K2" note.

### A3 — Octave (Ro → Ro′) error > 25 cents

- **What:** if the bore axis isn't a true cylinder (taper, ovalization, or wander from deep-bore drilling), the second harmonic will land off-octave even when the fundamental tunes cleanly.
- **Why it matters:** octave errors are not tone-hole-tunable. They require re-shaping the utaguchi or accepting the prototype as a study artifact.
- **Test:** validation.csv `octave` row. Threshold ±25 cents = soft fail; > 50 cents = hard fail.
- **Mitigation:** post-bore `validation.csv` rows measure ovalization at three stations; reject blank if ovalization > 0.005 in.

## Structural risks

### S1 — Wall thickness too thin around hole 4 / thumb hole

- **What:** with a 1.10 in OD and 0.787 in bore, nominal wall is 0.157 in. A 0.394 in tone hole (Ø ≈ wall × 2.5) leaves wall on either side of the hole-edge of only ~0.157 − 0.394/2 in × cos(angle), and any local thinning during turning could push it below the structural margin.
- **Why it matters:** thin wall around a hole edge can crack during finger pressure or seasonal humidity swings.
- **Test:** post-turn `validation.csv` row "wall thickness at hole 4 station". Reject blank if any quadrant < 0.140 in.
- **Mitigation:** keep OD at 1.10 in (no decorative beads / coves on the prototype). Use cherry first (relatively crack-resistant); if a different species shows splitting, switch to hard maple.

### S2 — Foot end-face splits during parting

- **What:** parting a turned blank at 21.5 in cleanly is a hand skill. A poor parting cut leaves a stress-riser end-grain rough that can chip while installing pin-centers, especially if grain run-out is steep.
- **Why it matters:** the foot end is the acoustic open end; a chipped foot changes effective length unpredictably.
- **Test:** visual inspection + caliper check post-parting. Reject any blank with end-face chip > 0.020 in deep.
- **Mitigation:** hand-saw the last 0.060 in instead of parting; sand flat on a disc sander.

## Manufacturing risks

### M1 — Bore wander > spec on production cherry

- **What:** the headstock-driven deep-bore drilling step is tooling-light and operator-dependent. Production cherry could wander > 0.080 in at the 18 in mark even after a clean scrap-stock validation pass.
- **Why it matters:** wander beyond spec wastes a cherry blank and forces a switch to staged drilling from both ends, which doubles setup time.
- **Test:** scrap-stock validation rows (mandatory before each production blank). If wander on production cherry then exceeds spec, log and switch to dual-end drilling for the remaining blanks.
- **Mitigation:** mandatory pine-scrap validation pass before each cherry blank. Pecks ≤ 1 in deep. Retract often.
- **Open question:** is steady-rest support behind the tailstock vise worth the setup time? Decision deferred until the scrap-stock data exists.

### M2 — Reamer chatter scores the bore wall

- **What:** the 20 mm reamer is a 24 in OAL slender tool. If reciprocated (pecked) it can chatter and leave spiral scoring on the bore wall.
- **Why it matters:** scoring increases damping and shifts pitch slightly flat; it also makes the bore harder to clean (chips lodge in scores).
- **Test:** post-bore visual inspection with bore camera or fiber-optic scope. Reject if scoring depth visible to the naked eye.
- **Mitigation:** single-advance reamer pass at 600 rpm with cutting oil. No retraction during the cut.

### M3 — Tool runout exceeds 0.005 in on first pilot

- **What:** Jacobs chuck runout, MT2 taper fit, and Jacobs-to-bit eccentricity stack up. If total runout > 0.005 in, the pilot bore wanders even on a perfect setup.
- **Test:** indicate runout with a dial indicator on the chuck before each session. Re-seat the MT2 taper if reading is high.
- **Mitigation:** clean the MT2 taper with isopropyl + lint-free cloth before each session. Tap the chuck onto the taper with a dead-blow mallet.

## Ergonomic risks

### E1 — Hole 4 reach exceeds player's index span

- **What:** Hole 4 (Ri / C5) sits at 12.95 in from foot. With holes 1–3 at 19.40 / 17.29 / 15.40 from foot, the four front holes span 19.40 − 12.95 = 6.45 in. A player with smaller hand span may not be able to comfortably reach hole 4 with the index finger.
- **Why it matters:** ergonomic non-fit means the prototype doesn't get played, which means it doesn't get tuned, which means the empirical loop never closes.
- **Test:** dry-fit on Tony's hand before drilling holes; mark the hole-1 and hole-4 positions with painter's tape and check span.
- **Mitigation:** the 1.8-shaku D4 standard places holes within the typical span of an adult shakuhachi player; this is well-established. If Tony's span doesn't match, the design is correct and player technique adapts. Annotate as "standard D4 1.8-shaku — adapt fingering, not geometry."

### E2 — Thumb hole misaligns with finger reach

- **What:** thumb hole at 11.54 in from foot, on the back face. If the player's thumb naturally sits at a different position when supporting the body, the thumb hole is unreachable while the four front holes are addressed.
- **Test:** dry-fit before drilling. Tape-mark the thumb position.
- **Mitigation:** Kinko-ryū tradition places the thumb hole roughly between holes 4 and 5 — slight forward offset is acceptable. Document if Tony shifts thumb position from canonical 11.54 in.

## Supply risks

### SP1 — 20 mm reamer back-ordered

- **What:** the 24 in OAL 20 mm reamer (SHK-SRC-007) is a specialty tool with longer lead times than the rest of the order. If back-ordered, the entire deep-bore step blocks.
- **Mitigation:** verify lead time at order placement. Fallback: rent a reamer or substitute step-down endmill in collet chuck (reduces final-pass quality but works).

### SP2 — Cherry quarter-sawn 1×1×24 sold out

- **What:** specialty turning blanks ship in small batches. A "buy 3" order can ship 1 of 3 with the rest back-ordered.
- **Mitigation:** order from Bell Forest Products (primary) and a backup supplier simultaneously. Cherry is the primary preference but hard maple and walnut backups are spec-compatible.

## Fit-and-finish risks

### F1 — Walnut oil cure fails (still tacky after 5 days)

- **What:** walnut oil cures by oxidation; cold or humid conditions slow cure to weeks. A tacky bore traps dust and changes acoustic damping.
- **Test:** light finger-press on cured surface; should not leave a print.
- **Mitigation:** cure at > 65 °F and < 60 % RH. If still tacky after 7 days, reapply thinner coat and re-cure under lamp warmth.

### F2 — Carnauba wax inadvertently inside the bore

- **What:** carnauba paste applied carelessly migrates inside the bore.
- **Why it matters:** wax film changes acoustic damping by ~5–15 cents (typically flat) and is unevenly distributed.
- **Mitigation:** plug both ends with painter's tape during waxing. Wipe outside only with a tampon-style applicator.

## Cultural risks

### C1 — Overstating tradition lineage on Western prototype

- **What:** the README or capstone deck overclaims that this prototype "follows the Kinko-ryū tradition" or similar. It does not — it's a Western luthier-shop solid-billet adaptation.
- **Why it matters:** misrepresentation is disrespectful to traditional makers and inaccurate.
- **Mitigation:** README + design.md + capstone deck all use the framing "Western solid-billet adaptation modeling shakuhachi acoustics, with respect for the Japanese Buddhist tradition." Specifically avoid claims like "authentic," "traditional," or "in the style of [named master]."

### C2 — Buffalo-horn inlay with unverified provenance

- **What:** if the buffalo-horn block is sourced without species verification, it could be a CITES-listed African black-buffalo (Synceros caffer) horn rather than the unrestricted water buffalo (Bubalus bubalis).
- **Mitigation:** order only from suppliers who specify *Bubalus bubalis* on the product page. Defer the inlay if provenance is unclear; the prototype works without it.

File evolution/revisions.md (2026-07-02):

# Revision Register — shakuhachi

| Rev | Date | Parent | Delta | Downstream artifacts invalidated |
| --- | --- | --- | --- | --- |
| A | 2026-07-01 | — | Stage 0 intake of current masters (cad/shakuhachi_master.scad + shakuhachi-design-table.xlsx + wolfram/shakuhachi-wolfram-model.wl). | none (no alpha/beta/production artifacts exist yet) |

Stage 0 only. Gate A has not been run; no Alpha compiles, vendor quotes, or production lock exist for this product. No physical prototype (SHK-D4-P1) has been built yet.

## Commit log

2026-05-02 Initial scaffold: Shakuhachi
    [shakuhachi-design-table.xlsx]
2026-05-07 v4 update
    [bom.csv, cut-list.csv, shakuhachi_master.scad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]
2026-05-29 [shakuhachi] V5 uplift: visual-output-register, mcp-session-log, family-spec, L2 status (Refs #1) (#5)
    Add visual-output-register.csv registering 7 drawings/ SVGs as derived_preview,
    cad/shakuhachi_master.scad as pending_measurement CAD source, hero jpg as reference_only,
    and wolfram starters as pending_measurement. Add cad/mcp-session-log.md (scad was
    sprint-agent-authored, no interactive MCP sessions). Add family-spec.csv L2 scaffold
    for SHK-D4-P1. Update README release status to V5 "Status: L2 V5 build-packet candidate".
    Refs #1
    [family-spec.csv, visual-output-register.csv]
2026-05-31 Add image-gen concept prompt; wire explorer images
2026-06-23 feat(wolfram): deploy interactive model + live explorer embed (#9)
    * feat: wire live Wolfram interactive embed into explorer.html
    CloudDeploy shakuhachi-wolfram-model.wl; regenerate explorer.html with live iframe.
    Refs tonykoop/instrument-maker#197
    * feat: wolfram embeds + updated explorer.html (Refs #197)
    * Wire 3 rendered concept image(s) into explorer gallery
    * feat(wolfram): deploy interactive model + live explorer embed
    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
2026-07-02 V5 packet refresh: status line, provenance, evolution intake
    Validator: 1 failure -> 0 failures (4 warnings, all expected
    pending_measurement). Fixed README Status line (was `**Status: L2 ...**`
    with colon inside bold, now `**Status:** L2 ...`). Kept cad/shakuhachi_master.scad
    unchanged (existing real master per V5 woodwind addendum); render check passes
    (openscad -o STL, exit 0). Added register + provenance rows for
    wolfram/shakuhachi-wolfram-model.wl (already merged from PR #9, source-only).
    Added evolution/ Stage 0 intake. Utaguchi (blowing-edge) geometry stays out of
    scope throughout.
    [visual-output-register.csv]
